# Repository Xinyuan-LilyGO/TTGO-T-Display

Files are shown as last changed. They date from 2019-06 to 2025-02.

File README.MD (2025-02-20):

# TTGO T-Display

## Quick start

1. **Install USB driver**, [CHxxx Series MAC driver](http://www.wch-ic.com/downloads/CH34XSER_MAC_ZIP.html) , [CHxxx Series Windows driver](http://www.wch-ic.com/downloads/CH343SER_ZIP.html),[CP21xx Series driver](https://www.silabs.com/developers/usb-to-uart-bridge-vcp-drivers?tab=downloads)
2.  Copy  **TFT_eSPI**  to the  **<C:\Users\Your User Name\Documents\Arduino\libraries>**  directory
3. Open **Arduino IDE,** find **TFT_eSPI** in the file and example, the **T-Display** factory test program is located at **TFT_eSPI -> FactoryTest**, you can also use other sample programs provided by TFT_eSPI
4. In the **Arduino IDE** tool options, select the development board  **ESP32 Dev Module**, **select Disable in the PSRAM option**, **select 4MB in the Flash Size option**, Other keep the default
5. Select the corresponding serial port. If you are not sure, please remove all the serial ports, leaving the board in the USB connection state, just select that one
6. Finally, click upload, the right arrow next to the tick
7. Please note that the highest version currently supported by TFT_eSPI is 2.0.14. Compiling with a version higher than 2.0.14 will result in an error. Please pay attention to the selection of esp32 version. `Tools -> Board -> Boards Manage -> Search esp32 -> 2.0.14 -> Install`

-------------------------
1. **安装 USB 驱动**, [CHxxx Series MAC driver](http://www.wch-ic.com/downloads/CH34XSER_MAC_ZIP.html) , [CHxxx Series Windows driver](http://www.wch-ic.com/downloads/CH343SER_ZIP.html), [CP21xx Series driver](https://www.silabs.com/developers/usb-to-uart-bridge-vcp-drivers?tab=downloads)
2.  拷贝  **TFT_eSPI**  到  **<C:\Users\你的用户名\Documents\Arduino\libraries>**  目录内
3. 打开**ArduinoIDE** , 在文件，示例中找到**TFT_eSPI**, T-Display出厂测试程序位于**TFT_eSPI -> FactoryTest**,你也可以使用其他TFT_eSPI提供的示例程序
4. 在**Arduino IDE** 工具选项中 ， 开发板选择 **ESP32 Dev Module**,**在PSRAM选项中选择Disable**， **Flash Size 选项中选择4MB** ，其它保持默认 
5. 选择对应的串行端口，如果不清楚请移除所有串行端口，之保留板子处于USB连接状态，选择那一个即可
6. 最后可点击上传即可，勾号旁边的向右箭头
7. 请注意，TFT_eSPI 目前支持最高版本为2.0.14 ，高于 2.0.14 编译则会报错，请注意esp32 版本的选择:`Tools -> Board -> Boards Manage ->Search esp32 -> 2.0.14 -> Install`

-------------------------
## SD card connection
- Demonstrate how to use the second SPI device, using the SD card as a demonstration device
- 使用SD卡作为演示设备,演示如何使用第二个SPI设备
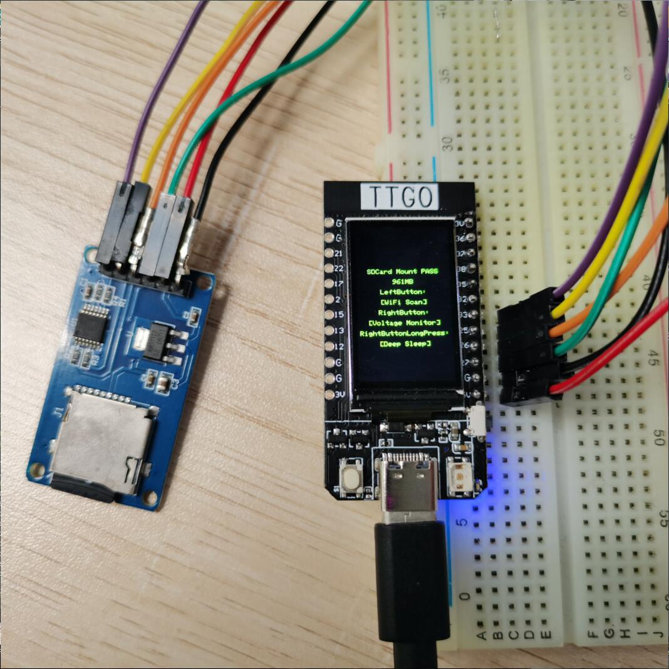
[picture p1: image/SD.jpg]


## Pinout
| Name | V18 |
| --- | --- |
| TFT Driver | ST7789 |
| TFT_MISO | N/A |
| TFT_MOSI | 19 |
| TFT_SCLK | 18 |
| TFT_CS | 5 |
| TFT_DC | 16 |
| TFT_RST | 23 |
| TFT_BL | 4 |
| I2C_SDA | 21 |
| I2C_SCL | 22 |
| ADC_IN | 34 |
| BUTTON1 | 35 |
| BUTTON2 | 0 |
| ADC Power  | 14 |

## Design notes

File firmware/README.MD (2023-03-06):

When you suspect that there is a problem with the hardware, you can brush in our test firmware

1. Download [Flash_download_tool](https://www.espressif.com.cn/sites/default/files/tools/flash_download_tool_3.9.3_0.zip)
2. Select esp32,UART
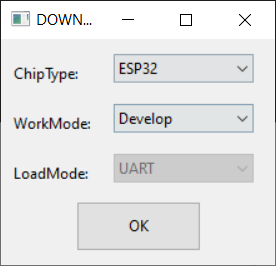
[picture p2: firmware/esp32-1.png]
    
3. Select according to the following figure, finally select START, press RST after writing, or power on again, and then observe the log output from the serial port
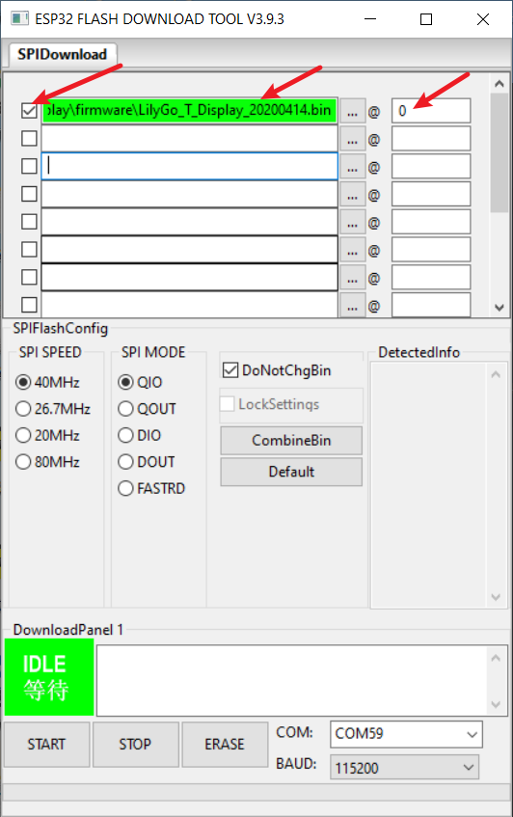
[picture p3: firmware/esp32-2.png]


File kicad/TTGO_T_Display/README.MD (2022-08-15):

# This is a KiCad library for TTGO_T_Display.
You need add "TTGO_T_Display.kicad_sym" as symbol library with name TTGO_T_Display to KiCad.
This file is in folder "symbols".
Also you need to add "TTGO_T_Display.pretty" folder as footprint library with name TTGO_T_Display to KiCad.
This folder is in folder footprints.

Library created by WolodiaM

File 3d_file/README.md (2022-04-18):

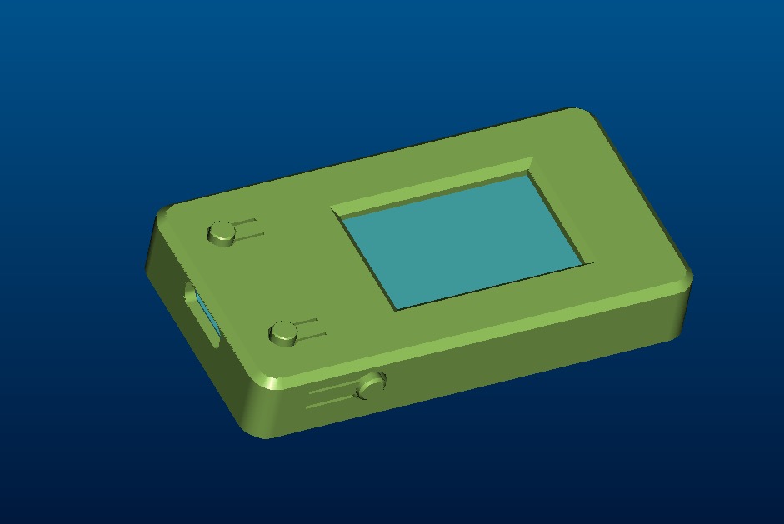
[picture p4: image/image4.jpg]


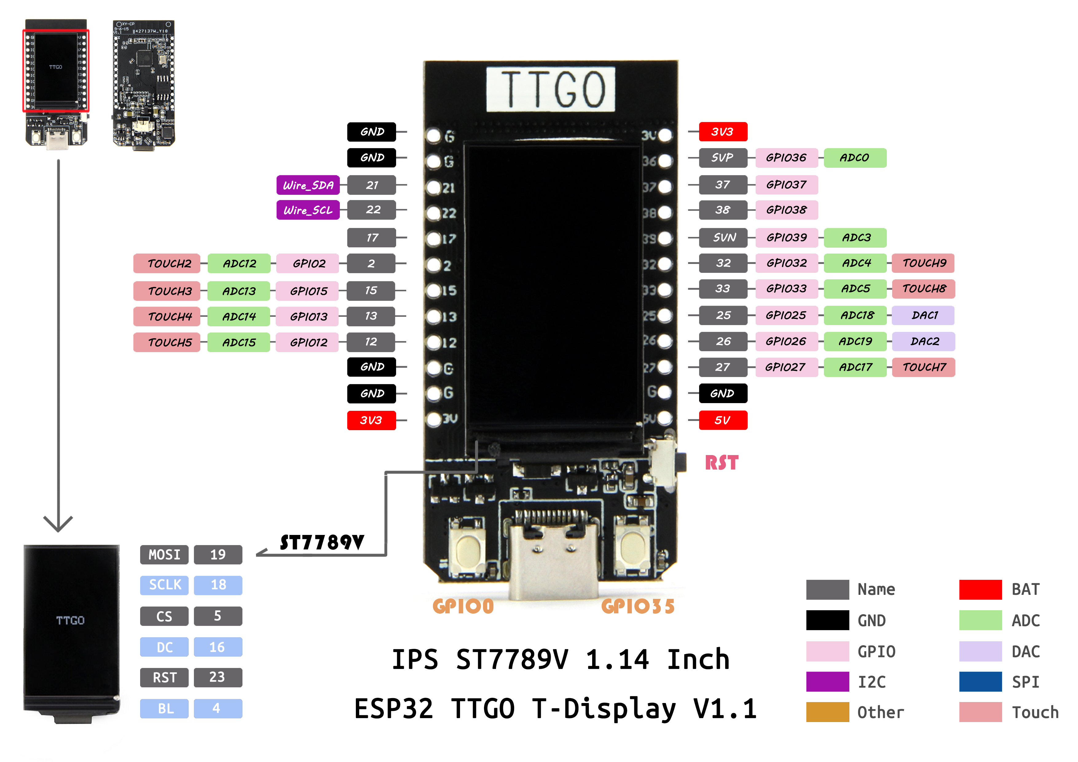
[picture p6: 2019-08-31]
image/pinmap.jpg

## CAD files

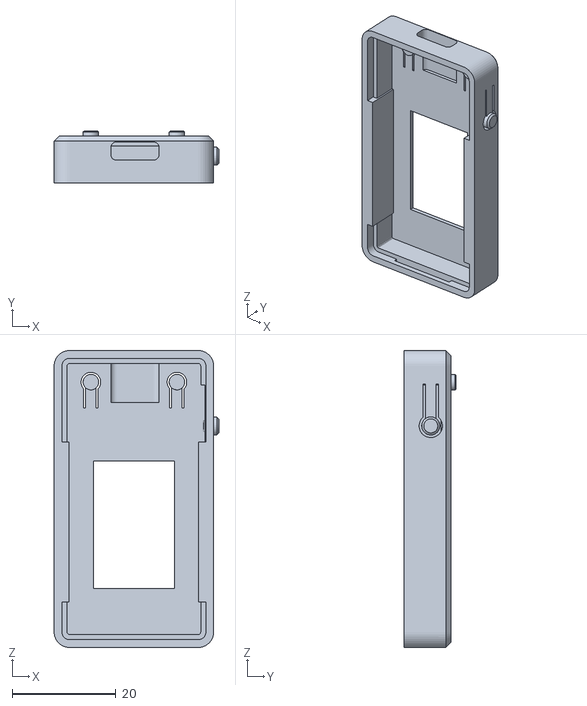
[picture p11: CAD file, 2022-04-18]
3d_file/prt0005_14(2).stl
31.8 x 10.1 x 57.3

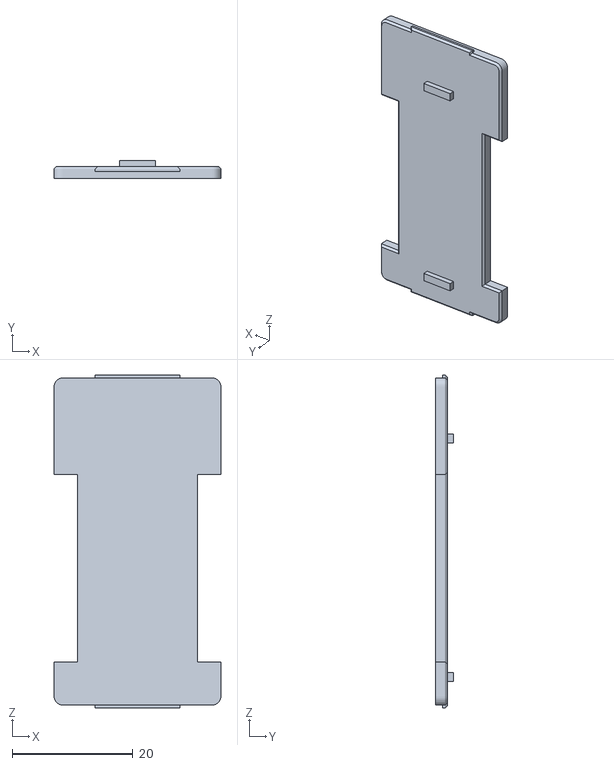
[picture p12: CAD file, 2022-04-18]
3d_file/prt0003_23.stl
27.6 x 3.00 x 55.1

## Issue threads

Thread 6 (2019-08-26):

PWR EN functionality

paccerdk, 2019-08-26:
I've been trying to figure out the functionality the PWR EN, but your schematics is difficult to figure out in this regard, and its not documented anywhere.

As far as i could figure out, the PWR EN "pin" is supposed to shut off the 3.3V regulator when powered by battery (and usb is disconected), but it does not seem to work (i've tried toggling it)

Joennuh, 2019-08-26:
Just a guess: maybe it is read only? So you can read the value and let your sketch find out in this way whether it runs from battery or USB power?

paccerdk, 2019-08-27:
@Joennuh its an output, there's a diode on the pin, restricting current flow to one direction.

gnunomad, 2019-09-22:
I have the same problem. I've been analyzing the scheme but I can't figure out how that pin works. I think the scheme contains errors in the polarity of the mosfet.

lewisxhe, 2019-10-08:
I get feedback: PWR_EN can continue to detect the power of the lithium battery when there is no USB power supply. V3V is to prevent leakage current. @paccerdk

paccerdk, 2019-11-17:
@lewisxhe
This isn't making much sense to me.
Detect in which way? As mentioned earlier, it appears to be an output, there is a [diode](https://github.com/Xinyuan-LilyGO/TTGO-T-Display/blob/master/schematic/ESP32-TFT(6-26).pdf) restricting the current flow to one direction. (out)
Could you perhaps share the feedback that you got?
Honestly, it seems to me like there is a mistake on the schematic, and the PWR_EN was supposed to be able to let the device turn itself off, when battery powered. that also explains the naming.

lewisxhe, 2019-11-18:
@paccerdk
In order to use VBA to turn on the power, because, when downloading 32, the single chip PWR_EN can not work, so V3V has no power, so 2104 can not be downloaded, so open V3V power through VBUS

The above is the original words, I am responsible for the transmission.

ricolk, 2020-03-17:
I cannot understand BAT offsheet. It is just connected to  Q4 and to the partition for battery conversion... Is it connected also to VBAT?

ticksp, 2020-04-01:
[ESP32-TFT(6-26).pdf](https://github.com/Xinyuan-LilyGO/TTGO-T-Display/files/4416932/ESP32-TFT.6-26.pdf)
For understand PWR_EN functionality you can have a look on comments, which I made in attached schematic.
So you can set PWR_EN to "1" and read voltage in BAT_ADC, if this voltage more than 4.3 V device have powered from USB. If less then 4.3 V - device have power from battery. To save battery you can set PWR_EN to "0" and in this case USB converter will be power off and do not use your battery. When you need to measure battery voltage first set PWR_EN to "1", measure voltage and then set PWR_EN back to "0" for save battery. I hope my descrition will help somebody to better use this device! :)

pvonmoradi, 2020-10-24:
@ticksp Thanks for the clarification. So the overloading of GPIO14 (as it is JTAG's TMS pin) does not hurt JTAG functionality right?
The way I see it, while debugging via JTAG, some transistors would get stressed (because of PWR EN) and the "BAT_ADC" voltage is not to be trusted, but nevertheless, this wouldn't hurt debugging.
#17 #26

tadam777, 2021-01-31:
It's possible to solder a wire on the bottom of the T-Display module to access the GPIO14. I didn't test it but here's where to solder :

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

posplayr, 2021-06-24:
Can anyone confirm that you can access IO14 at D6 in order to support JTAG and have the JTAG work?

Also it seems as if from ticksp's comment above:
**_When you need to measure battery voltage first set PWR_EN to "1", measure voltage and then set PWR_EN back to "0" for save battery._**

if not using a battery then D6 be removed and this makes it easier to solder a wire to the anode pad of D6?

kiromaisus, 2021-08-15:
Yes, it's possible to solder a pin on one end of the diode that's connected to IO14 and use JTAG. I did it with ESP-prog and it worked. Not needed to remove the diode, but I'm not using it with battery, just to debug.

posplayr, 2021-08-18:
> Yes, it's possible to solder a pin on one end of the diode that's connected to IO14 and use JTAG. I did it with ESP-prog and it worked. Not needed to remove the diode, but I'm not using it with battery, just to debug.

Thank you for that confirmation.

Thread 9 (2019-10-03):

Auto power-on when powered trough battery or 3.3v/5v pins

oniongarlic, 2019-10-03:
Is it possible to get the board to power-on automatically when powered trough the battery or 3.3v/5v pins ? At least my board requires a press of the reset button for it to start up.

When powered trough USB-C it turns on automatically, but unfortunately I can't use that in the final installation.

Joennuh, 2019-10-03:
It is actually too bad that the device hasn't got an reset-pin. When it does have an reset-pin you could attach an external reset-button to it.

lewisxhe, 2019-10-08:
This problem has been feedback, you can remove the marked position capacitance in the figure can be solved @oniongarlic
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

oniongarlic, 2019-10-10:
Thank you, I will try that.

smartynov, 2019-12-01:
@oniongarlic did it help you?

Jeopardye, 2019-12-08:
Can confirm, this works. (Which is good, because there is no way I could solder this back in. The brute force from the screwdriver probably didn't help much either...)

cc @smartynov

austrisv, 2020-01-12:
Did help for me as well ... for one or two reboots. Then suddenly it was not connecting to wifi anymore. Checked the console and upon reset can see "waiting for download" and
rst:0x1 (POWERON_RESET),boot:0x3 (DOWNLOAD_BOOT(UART0/UART1/SDIO_REI_REO_V2))

If I do upload from Arduino - it succeeds and then this. As if I would be holding gpio0 to ground on restart (where I even can't spot the gpio0 on the board).

Dear @lewisxhe, could it be related w removal of capacitor? Any other ideas what could have gone wrong? Thank You!

lewisxhe, 2020-01-13:
@austrisv Because it is GPIO0 to control the download and start, there is only the reason for this capacitor. This is the conclusion that I use the battery to connect the board and the UART output.

kostashellas, 2020-01-23:
what's the solution to this issue?
for my project I need power on when 5.3v connected to +5v pin (works only if RESET button triggered) and WiFi connection right after the power on.
C3 cap 100nF can be reduced to have both functions available?

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

john4242, 2020-02-11:
Same issue. After looking at the schematic, I'm not sure the VBUS (USB) doesn't have this power issue either, maybe the USB-TTL chip is sending an RTS signal on power or computer connection, and that is doing the reset?
CHIP_PU seems to be the reset pin on the schematic?
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

hpsaturn, 2020-05-09:
Same issue for me, after some hours, with the USB-C connected and the application running, it turn off. The only mode for turn-on it is with the reset button. It is a very bad behaivor for aplications 24/7 :'(

spiff72, 2020-05-28:
Has there been any additional info on this topic.  This is still a struggle for me.

I have several of these boards and I want to power them from the 5v pin (no battery needed).  But if they are disconnected from power, pressing the reset button to restart them is a pain.

I even see different behavior between boards (with different code loaded).  One seems to start up fine when 5v is connected to the pins, and the other goes into a state where it is drawing about 20ma of current and won't boot until the reset button is connected.

Can the code itself somehow prevent this behavior?  Or the bootloader?  The one that absolutely refuses to start without the reset button push has been loaded with a bootloader i donwloaded from a support thread from the WLED developer, so this makes me wonder if that might be contributing to the issue in my case.

spiff72, 2020-05-28:
UPDATE:  I just flashed the bootloader to the board that seems to start up correctly with the 5v pins, and after doing so, it still operates normally (no push of the button needed).

tehcaster, 2020-06-01:
> UPDATE: I just flashed the bootloader to the board that seems to start up correctly with the 5v pins, and after doing so, it still operates normally (no push of the button needed).

So what you're saying is, if the board boots on 5V pin without pressing reset, flashing the bootloader will not break that. But also if the board does *not* boot without pressing reset, flashing the bootloader also will not change that. Correct?

So the question is, what makes the difference between boards that boot and boards that don't? Of those few I have, none boots without reset. It's really a setback on otherwise great board, I wish the reset was included in the pin header. Did anyone e.g. try to desolder the built-in button and wire it away from the board?

spiff72, 2020-06-01:
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

I have an update to my previous work...
I ended up building soldering up a board (in a printed enclosure) with this TTGO T-Display over the weekend.  I am running the WLED project on it (https://github.com/Aircoookie/WLED/) - which I submitted a pull request for over the weekend as well to roll in a usermod that allows for the use of this TTGO T-Display with that WLED project and Platformio.
My arrangement is as follows:
- 12v power supply plugs into a barrel connector in the enclosure
- The 12v power supply passes through to the addressable LED strip I am using (WS2815), and I also have a small buck converter in the enclosure that drops the voltage down to 5v to power the TTGO board and a level shifter (for bumping the data signals of the TTGO up to 5v to feed the LED strip).

I just unplugged it 4 times in a row, and plugged it back in, and it powered up successfully (fully booted) without any need for a push of the reset button.

I can't recall for certain which of the boards I used for this build, but I am fairly confident that it was the one that was loaded with the clock program I referenced earlier in this thread.

I have no explanation as to WHY this is now booting without issues.  I think I did notice just one instance where it didn't boot up after initial connection to power (right after i built it), but unplugging the 12v power and plugging it back in allowed it to fire up just fine.

The only difference between this situation and the one I was testing before is that I am powering it with the 12v --> 5v buck regulator instead of my Agilent E3646A bench supply (at 5v).

This may not help others very much - but I just wanted to share my results...

sej7278, 2020-09-20:
So what's the solution to this? Seems removing the capacitor stops it from booting or something? Lots of gibberish in this thread!

sej7278, 2021-04-08:
@lamello have you tried the lipo connector?

spiff72, 2021-04-08:
Just to chime in here again, I have built several more of these WLED controllers using this board and have not had issue using the approach I described above.  I did not modify the boards in any way and they "just work" in my case.  Not sure why others don't...

lamello, 2021-04-08:
No i didn't try the lipo connector (because i will not use it in my project). As i said before i did powered directly the board with 3.3 Volt and the board won't start either.
When i look at the schema, i have a susspicion of the CP2104. The difference between powered by USB and direct (5v/3.3V) is that the CP2104 has power with the USB and not with the direct voltage. The CP2014 controls the DTR and RTS and these lines has something to do with the CHIP_PU signal. I have programmed now for several months for the project and the program  begins to get really nice, so this hardware issue is a bummer. I use almost no pins (just i2c and an pin for interrupt. I really want to use this board because is is compact and has a beautiful little display. I will look further for the issue, but i have now no problem to connect the CHIP-PU signal to an unused IO-pin and to externaly reset it (maybe with an attiny). Will see.

sej7278, 2021-04-08:
I wouldn't use a TTGO display in a final product it's just too unreliable and no two boards seem to work the same.

I'm currently prototyping on the Display  then moving to a Mini with a separate tft for the finished product

lamello, 2021-04-08:
@sej7278: What do you mean by "a Mini". I have worked with a mini, but that was a DEC PDP11. ;-)

sej7278, 2021-04-08:
TTGO T7 Mini https://m.aliexpress.com/i/32977375539.html

lamello, 2021-04-15:
Thanks for sharing.

I haven't solved it, but have now a workaround. I have made a wire from the reset switch to Pin26 (which is not used in the project).
I have programmed an attiny85 which generate a 150ms negative pulse at his startup. The attyny is powered by the 3.3Volt of the TTGODisplay. Connect the pulsepin of the attiny to pin26 of the TTGODisplay with an 120 Ohm resistor and voila, the TTGO boots when it is powered with 5Volts.
I know, it's overkill, it won't win the beauty contest. But it boots now.
I'm done with it.

Greetings lamello

trycoon, 2022-09-18:
I can confirm that unsoldering the capacitor works for three of my TTGO-T1 boards, that normally require the reset button to be pressed to power on. This is when powering the board from the 5V pins.
A fourth board works without this hack, so there may be different revisions of the board.

CLGamesStudio, 2023-03-09:
Help me please! I flashed the board several times, but after loading the Tetris game on it, it stopped being displayed on the device panel, when the PC board is connected, it sees it, but when I try to load a new program, the com port disappears from the list. Thank you in advance

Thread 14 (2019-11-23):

SPI PINs - connect to SPI device

DavidAntonin, 2019-11-23:
It is possible connect external SPI sensor - C1101 433MHz transceiver?
On generic ESP32 I use pins:
18	(SCK)
19	(MISO)
23	(MOSI)
5	(SS)
Thank you

lewisxhe, 2020-01-08:
Since 14pin of HSPI is already used, the following combinations can be used
CS 15
CLK 25 or 26,27
miso 12
mosi 13
 
21,22 is also possible, but generally used as SDA SCL for I2C

ketan, 2020-02-11:
This pin mapping definitely did not work.

```cpp
#define PIN_MISO  12
#define PIN_MOSI  13
#define PIN_SCK  26
#define PIN_CS  15
```

I'm getting the following error, it appears that the esp32 is unable to read its own memory, unplugging the microsd module seems to atleast print some debug logs via serial.

```
rst:0x10 (RTCWDT_RTC_RESET),boot:0x33 (SPI_FAST_FLASH_BOOT)
flash read err, 1000
ets_main.c 371
ets Jun  8 2016 00:22:57
```

Has anyone managed to get an sd card to work with this TTGo board, could you share your pin mappings?

ketan, 2020-02-11:
Found the answer, the following pin mappings worked for me:

```
#define PIN_MISO  27  // GPIO27
#define PIN_MOSI  26  // GPIO26
#define PIN_SCK   25  // GIPO25
#define PIN_CS    33  // GPIO33

...
SD.begin(PIN_CS, PIN_MOSI, PIN_MISO, PIN_SCK)
```

romatou18, 2020-03-03:
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

I found out the same thing: trying to use the remaining available HSPI pins i.e. 15,13, 12 does NOT work at all. Tried it very hard, the only thing that works is using other generic GPIOS with the VSPI, although it's not as good as HSPI since the max clock speed is only 26MHZ if im correct vs. 40MHZ for HSPI. But using an SD card reader on SPI seems to work great, decent writing speed, way enough for logging text.

If it was coming to writing a video stream real time from a camera that would likely be an issue. Anyway other modules like the TTGO Camera module are made for that.

Now the big problem that remains is the fact that PIN 14 is the MS JTAG pin and therefore this is impossible to do JTAG debugging on TTGO-T Display. I found that out too late. Not an issue for production once the program works ok. But for development work this is a real issue. I am now thinking of developing my project on a different board.

RideOn123, 2020-05-09:
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

Which SD Libary did you use? The "standard" Lib expects different arguments for SD.begin().

ketan, 2020-05-09:
I'm using Arduino api on esp32:
https://github.com/espressif/arduino-esp32/blob/master/libraries/SD/src/SD.h

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

minkione, 2020-05-28:
I am trying to get working a CC1101 with my T-Display.
Someone suggested to device the following pins as SPI for teh connection between the T-Display and the NRF24...
MISO: 27
MOSI: 26
SCK: 25
CSN: 33
GDO0: 2
GDO2: 37
But it still doesn't work.

Anyone has some suggestions?

lewisxhe, 2020-06-28:
@minkione

As shown in the code below, did you specify SPI to initialize it?
```
#include "FS.h"
#include "SD.h"
#include <SPI.h>

SPIClass SPI1(HSPI);

#define MY_CS     15
#define MY_SCLK   25
#define MY_MISO 26
#define MY_MOSI 27
void setup()
{

    SPI1.begin(MY_SCLK, MY_MISO, MY_MOSI, MY_CS);

  //Assuming use of SPI SD card
    if (!SD.begin(MY_CS, SPI1)) {

        Serial.println("Card Mount Failed");

    } else {
        Serial.println("DEU CERTO INICIAR SD CARD");
    }
}
```

minkione, 2020-06-28:
Yes, I defined them in my sketch:
```
//ELECHOUSE_cc1101.setSpiPin (SCK, MISO, MOSI, CSN);
ELECHOUSE_cc1101.setSpiPin(25, 26, 27, 15);  //Default LSatan Configuration For T-Display
```

In case you wanna try with a CC1101, I used this sketch
https://github.com/LSatan/SmartRC-CC1101-Driver-Lib/blob/master/examples/Rc-Switch%20examples%20cc1101/ReceiveDemo_Advanced_cc1101/ReceiveDemo_Advanced_cc1101.ino

from the https://github.com/LSatan/SmartRC-CC1101-Driver-Lib

minkione, 2020-06-28:
For instance, I tried with different boards, ESP32 Wroom, ESP8266, UNO R3, MEGA2560.
The only board so far that doesn't work and cannot figure out why the SPI pins do not work... is the T-Display one...

minkione, 2020-06-28:
I have even added this:
  SPIClass SPI(HSPI);

here:
https://github.com/LSatan/SmartRC-CC1101-Driver-Lib/blob/master/ELECHOUSE_CC1101_SRC_DRV.cpp#L69
```

/****************************************************************
*FUNCTION NAME:SpiStart
*FUNCTION     :spi communication start
*INPUT        :none
*OUTPUT       :none
****************************************************************/
void ELECHOUSE_CC1101::SpiStart(void)
{
  // initialize the SPI pins
  pinMode(SCK_PIN, OUTPUT);
  pinMode(MOSI_PIN, OUTPUT);
  pinMode(MISO_PIN, INPUT);
  pinMode(SS_PIN, OUTPUT);

  SPIClass SPI(HSPI);

  // enable SPI
  #ifdef ESP32
  SPI.begin(SCK_PIN, MISO_PIN, MOSI_PIN, SS_PIN);
  #else
  SPI.begin();
  #endif
}
```

minkione, 2020-06-28:
And to be sure... I also tried by replacing all existing occurrences of "SPI." with "SPI1."

https://gist.github.com/minkione/795307620dbb93723678fcec3ff19368

No luck in getting CC1101 working...

lewisxhe, 2020-06-29:
I have tried using the SD card and everything is working, the code and README have been updated

pati5000, 2020-07-08:
@minkione you swapped the MISO and MOSI pins by mistake.

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

See the original post from @ketan

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

Hope this helps. All the best

flyandi, 2020-07-29:
So for anyone still having issues. Both HSPI and VSPI are working BUT you need to ensure you connecting  it right. I had issues with the actual pin-out of using an TF Card Holder and just "blindly" followed the pictures. Turns that both are wrong.

Here is the correct pin out on both the Micro SD and the adapter:

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

Biggest feedback is there that PIN 1 is NOT CS.. I repeat PIN 1 is NOT CS .. PIN 1 is not used for SPI and PIN 2 is CS .. after that it worked without flaws both on HSPI (40mhz) and VSPI (26mhz) ...

tadam777, 2021-12-12:
>

Just confirm it's possible to JTAG debug by soldering the required IO14/TMS pin under the board : https://github.com/Xinyuan-LilyGO/TTGO-T-Display/issues/6#issuecomment-770394385

Closed 2020-06-29.

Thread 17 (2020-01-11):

is there a way to connect JTAG debugger to the processor on this board ?

anonymouze, 2020-01-11:
I can't see any JTAG pins in the schematics. Need to set up a debugger.

lewisxhe, 2020-01-13:
Unfortunately, JTAG cannot be used for debugging

bastianhjaeger, 2020-05-28:
Is there any other way of debugging? E.g. via the USB?

pvonmoradi, 2020-10-24:
@lewisxhe Out of 4 required JTAG pins, only GPIO14 (MTMS/TMS) is not available. What is this "PWR EN" that is connected to it? Following the schematics, it seems it is attached to D6 diode.

tadam777, 2021-01-31:
To test but the pin GPIO14 can be accessed under the board : https://github.com/Xinyuan-LilyGO/TTGO-T-Display/issues/6#issuecomment-770394385

robertlipe, 2021-03-14:
If you need JTAG in this form factor, the Longan Nano does have JTAG brought opposite the USB connector, making it a real pain on breadboard since

I wish I'd noticed lewisxhe's comment before, as I ordered this to step up (over?) from Longan Nano just in the hopes of having a better video display controller. That sentence really puts the hurt on using this in development.

I was just told by B*d that this device was discontinued. I can't tell if that's from them or by the maker, but they DO seem to be getting rarer.

Off to Plan D for an inexpensive, self-contained RISC-V development/debugging environment with a screen.

robertlipe, 2021-03-14:
@lewisxhe , now that I look at it, are you sure? I'm looking at the Longan Nano and my (dysfunctional) T-Display and all the JTAG pins are in the same place.  In the GD32V Manual (500+pages), section 7.4.3 says the packages with low pin count (e.g. the one used here) can be reconfigured to remap the JTAG from (non-existent) pins.  The mappings are exactly the silk screens on this board and in the same location as they are on the Nano. 7.3.1 and 10.2.1  says the startup values of the GPIO lines out of reset should work for JTAG.

7.5.9 shows that SWJ_CFG[2:0] defaults to remapping being on and "The default state after reset is SWJ
ON.This allows JTAG mode to be enabled by sending a specific sequence on the JTMS/JTCK pin."

I wonder if this really IS the same as the NANO and it's just a silkscreen labeling issue that makes it look like JTAG isn't available.

TMS is one of those that gets remapped.

Can anyone with a working board try the pinouts from https://wiki.segger.com/SiPeed_Longan_Nano or offer a definitive reason why this doesn't work?

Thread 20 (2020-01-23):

Unable to read the battery voltage when USB is disconnected

yellowbeak, 2020-01-23:
When power is connected via USB, I can read the ADC value on pin 34, which is the BAT_ADC signal on the schematic and is half the supply voltage.

However, if I connect a LiPo battery, and disconnect the USB, this pin always returns a value of 0.

I have tried setting pin 14, which is PWR_EN as an output, and setting both HIGH, and LOW, but neither of these change the value I'm reading from pin 34 - it always reads 0 when running from battery.

How can I read the battery voltage when running from the battery without the USB connected?

bbogdanmircea, 2020-01-24:
I have just tried this board yesterday with the code from master and it shows the battery voltage on the display even when USB is not connected.
What code are you running on the board?

yellowbeak, 2020-01-24:
Sorry - you are correct.  I went back to the original example and it works as expected.  I was using a modified version of this, that incorrectly reconfigured one of the pins by trying to read it as a touch input, which gave the problem that I was seeing.  Once I removed this, it all works as expected.
Please delete this issue thread.

Closed 2020-01-24.

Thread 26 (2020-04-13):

PWR_EN on IO14

mhannebert, 2020-04-13:
I'm not sure what the "PWR_EN" is for...

It is connected to IO14
In the demo code, there is  a "#define ADC_EN 14" but this ADC_EN is not used further...

It is related to the ADC ? I don't think so. To measure the voltage of battery, this is IO34.
It looks like it is triggering one MOSFET which is linked to the battery?

mhannebert, 2020-04-15:
The demo code was updated in this respect just a few days after my comment above.

It looks like the PWR_EN set to HIGH enables to measure the batterie itself. Otherwise, it measures the voltage provided by USB? I'm not sure.

Not tested yet.

pvonmoradi, 2020-10-24:
Same question here. Since GPIO14 is JTMS, this essentially causes the board to lose support for JTAG debugging.
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

tadam777, 2021-01-31:
It's not too complex to access this pin and/or remove the diode : https://github.com/Xinyuan-LilyGO/TTGO-T-Display/issues/6#issuecomment-770394385

bbogdanmircea, 2021-02-16:
Can anybody explain according to the schematic what happens when this PWR_EN is high or low?

jej, 2021-02-27:
Here: #6

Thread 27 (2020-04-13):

How to power the board?

mhannebert, 2020-04-13:
I want to power the board without the USB.

Should I provide 5V to the "5V" pin?
Should I provide 3.3V to one of the "3V3" pins?
Would any of the above work?

I guess that if I provide 3.3V, the battery won't charge. But will it charge if I provide 5V?
It looks to me that only USB, through the TP4054, would enable the battery to charge...

M

JoeBarouneD, 2020-04-13:
Like any ESP32, you "normally" can power it by 5V or 3.3V.
I don't know if it can "step up" from 3.3v to Vcharg, you can try and report the result.
But i think it will work without problems on 5V.

flyandi, 2020-04-15:
I run it off a 1s lipo without issue.

spiff72, 2020-05-27:
Rather than attempting to create a new issue - I am looking for some help here.

In order to power this TTGO T-Display board with a voltage source (not through the USB-C connector), how would one go about this?

Are you connecting 5v to the 5V pin?  Or 3.3V to the 3.3V pin?  The 3.3v pin appears to be the output of the 3.3V regulator, so I am not sure that is the right approach.

And from my (unprofessional) look at the schematic, it seems like a 5V source would ideally be connected to the VBUS line, but that isn't broken out to a pin.

Am I missing something here?

I was hoping to use these for a project where I mount it in an enclosure, with a 12V input from a wall wart, and a small buck regulator to drop the voltage to 5v to power this and a level shifter for controlling some 12v addressable LEDs.  But not being able to power from that 12V source makes this board a bummer for me.  Even if it could be externally powered with a 3.3v source, I could put a second buck regulator in there for the 3.3v source and make it work.

But I have also seen some mentions that the board doesn't start "automatically" when power is applied through a method outside of the USB-C port.

JoeBarouneD, 2020-05-28:
Powering it by the JST connector is working (you can put a 18650 bat to test).
I could power it by USB-C with some voltage range.

Powering it by the 5V should work.
Just try it.

sej7278, 2020-09-20:
I can't get the battery connector on the underside to turn on the display, it seems to run a IR-LED i have hanging off the 5v pin (and I assume the ESP32 itself) but I can only get the display to turn on when running from USB-C. Does the display need 5v?

ribbles, 2020-10-31:
If I power via 5v rail, 5.0v is sent to the LiPo battery, so it looks like it is passing battery management. If I power via USB-C, 4.2v is sent to the LiPo battery. So I am unable to use battery management unless using the USB-C port, since there is no VBUS connector. I guess I could remove the USB connector and solder on to that, but that just makes it difficult to improve the software later on.

@sej7278 - I am able to run the controller & screen using just a LiPo battery plugged into the JST port, and also via the 3.3v rail.

I am using this schematic for reference: [https://raw.githubusercontent.com/Xinyuan-LilyGO/TTGO-T-Display/master/schematic/ESP32-TFT(6-26).pdf](https://raw.githubusercontent.com/Xinyuan-LilyGO/TTGO-T-Display/master/schematic/ESP32-TFT(6-26).pdf)

sej7278, 2020-10-31:
@ribbles when you run the controller and screen using a lipo, do you need to press the reset button to make the screen come on?

ribbles, 2020-11-01:
No. But my board was shipped without a capacitor next to the USB-C port, which I read is what needs to be removed here: [https://github.com/Xinyuan-LilyGO/TTGO-T-Display/issues/9](https://github.com/Xinyuan-LilyGO/TTGO-T-Display/issues/9)

madameczek, 2021-03-10:
> If I power via 5v rail, 5.0v is sent to the LiPo battery, so it looks like it is passing battery management. If I power via USB-C, 4.2v is sent to the LiPo battery.
...
> I am using this schematic for reference: https://raw.githubusercontent.com/Xinyuan-LilyGO/TTGO-T-Display/master/schematic/ESP32-TFT(6-26).pdf

Are u sure that 5V from rail is passed to a batterry connector or U6 batt management chip? I didn't test, but can't see this from schematic.

ismailagir, 2021-04-18:
Do 3.3V output also works when a lipo is connected?

ribbles, 2021-04-19:
Yes.

AdamM68, 2021-04-20:
still there is NO answer how to power the board/display other way than the USB-C connector.
I'm also looking for the easy answer - solution : how to power this device (not by USB-C) ?
- which pin should I use with 5v to make it work the same way as it works during USB-C powering ?
-

tadam777, 2021-04-30:
I'm powering it by the 5V pin, without using a battery or USB and it works fine.

itamardv, 2021-05-24:
Still without answer about how to use a battery and the back connector to power this thing?

dan-glass, 2021-05-24:
I connected the supplied power connector cable to a 4.7v lithium battery, and charge via the USB port. Works reliably and performs battery management.

perlix, 2022-07-26:
Two T-Display boards that I bought in early 2020 cannot be powered over their 5V pin. Three recently bought ones can, so there may have been a revision.

Shohreh, 2022-11-26:
I know nothing about electronics.

The TTGO has no on/off switch for the battery.

What compact switch could I use, so that I don't have to plug/unplug the JST cable each time?

Thank you.

flashtel, 2022-12-09:
I tried powering via the 5vdc and one of these

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

The GPS has 12 satellites but keeps loosing fix.

I plug the USB in disconnect the 5v drive, rock solid fix. Bring it in side it get's down to 4 sats and has rock solid fix.

It's also show batt volts when there is no battery attached when you drive it via the via 5 volt pin.

I'm going to either modify a USB plug or try and get something onto the back of the USB.

Thanks

codiak6335, 2023-01-03:
5v on the 5v pin just fried the board.

While I don't mind paying for learning... the time it takes to replace the boards... ARGH

Has any got a reliable solution?  can I power the 3.3v with 5v safely?

flashtel, 2023-01-03:
Hi,

I cooked mine also.

The only solution I can come up with is power it directly through the USB port.

I tried to pick up the line behind the USB connector but it was too fine for my soldering iron.

https://github.com/Xinyuan-LilyGO/LilyGo-LoRa-Series/blob/master/schematic/LilyGo_TBeam_V1.1.pdf

I would buy a mini usb connector and power it through there.

It's going to be ugly with a usb connector sticking out but I wish I had done that, rather than where we are both now.

After I fried it, I tried to replace the AXP192 chip, I think the problem is down stream from that, it didn't work.

I then tried a T-Motion board, which worked really well for about 7-8hours then it lost GPS fix, restarted wouldn't work.

Waited overnight, restarted it worked for another 7 hours and now the GPS is coming up as not recognised on boot.

I checked all the voltage test points and the 5v supply for noise/spikes looks good.

I have a badge/t-echo as well, it works really well with low GPS signal, I think the quectel L73K GPS is better than the Ublox M8N, after about 30 hours the e-paper screen has gone U/S.

3 out of 3 hardware faults.

I spent a lot of time on this, not sure I want to spend anymore.

Thanks

From: "Charles Jones" ***@***.***>
To: "Xinyuan-LilyGO/TTGO-T-Display" ***@***.***>
Cc: "paul" ***@***.***>, "Comment" ***@***.***>
Sent: Tuesday, 3 January, 2023 11:05:54 AM
Subject: Re: [Xinyuan-LilyGO/TTGO-T-Display] How to power the board? (#27)

5v on the 5v pin just fried the board.

While I don't mind paying for learning... the time it takes to replace the boards... ARGH

Has any got a reliable solution? can I power the 3.3v with 5v safely?

—
Reply to this email directly, [ https://github.com/Xinyuan-LilyGO/TTGO-T-Display/issues/27#issuecomment-1369348359 | view it on GitHub ] , or [ https://github.com/notifications/unsubscribe-auth/AEDG3I2ECRRX7GLBKJQ4MP3WQOJRFANCNFSM4MG24SLQ | unsubscribe ] .
You are receiving this because you commented. Message ID: ***@***.***>

codiak6335, 2023-01-03:
I can add a 5v to 3.3v regulator inline... but seems a waste

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

--
Cheers,
    Chuck

"It's not about how deep you went; it's about how long you stayed."

Rule the bottom - Rebreathers!

Esantacruz01, 2023-02-15:
I had the same problem to power the board/display other way than the USB-C connector. Some boards doesn't work powering 5V from external. The board just works from USB-C connector.
Solution: To power from battery or from external source you need to add these two lines at beginning of your coding setup() function (Arduino IDE). Lines are pinmode(15,OUTPUT); digitalWrite(15,1);
Thios will enables the pin for external power.
I hope that helps.

elpidiovaldez, 2023-03-02:
Is it not possible to power the board from 5V connected via the JST ? As far as I can see the charger chip (TP4054) allows battery voltage in range -0.3-7V, so 5V should not be a problem.  It is not going to try to charge a battery at that voltage, even if USB power is connected.  The 3.3V regulator allows input up to 6V, so that should continue to work.  I believe the other circuitry should prevent the USB supply fighting the battery input.  Am I missing anything ?  Has anyone tried it ?

Esantacruz01, 2023-03-02:
> Is it not possible to power the board from 5V connected via the JST ? As far as I can see the charger chip (TP4054) allows battery voltage in range -0.3-7V, so 5V should not be a problem. It is not going to try to charge a battery at that voltage, even if USB power is connected. The 3.3V regulator allows input up to 6V, so that should continue to work. I believe the other circuitry should prevent the USB supply fighting the battery input. Am I missing anything ? Has anyone tried it ?

Hi Valdez.
I am unable to power up from the JST too.
Looks like this issue is related to some version revision of these boards....Some works, some doesn't. My lot of 10 boards just powers up from the USB-C. That's why you need to add the lines above in your coding...

elpidiovaldez, 2023-03-03:
What does GPIO15 do ?  On my schematic it does not appear to be connected to anything.

jessedmatlock, 2023-04-22:
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

Thank you for the clarification!

erazor83, 2023-09-04:
Thanks for this issue. I also was wondering how to power via external 5V.

Using the battery input did not work for me. Fortunately I also didn't fried my board cos I noticed it's getting warm when I connect to the 5V PIN.

I connected an unused NC PIN directly to PIN 4 of the charger, see attached photos.
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

Achref-omrani, 2024-02-05:
> Powering it by the JST connector is working (you can put a 18650 bat to test). I could power it by USB-C with some voltage range.
>
> Powering it by the 5V should work. Just try it.

Does this apply for both lipo and lion batteries ? It only needs to be 3.7v that's it the type do not matter ?

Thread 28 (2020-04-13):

Eagle library

mhannebert, 2020-04-13:
Did anyone create the library for use of this board in an Eagle project?

If not, I'm going to do it and share ;)

flyandi, 2020-04-15:
I made one a while ago. Attached. Also added as PR.

https://github.com/Xinyuan-LilyGO/TTGO-T-Display/pull/29

[TTGO-TDisplay.lbr.zip](https://github.com/Xinyuan-LilyGO/TTGO-T-Display/files/4478957/TTGO-TDisplay.lbr.zip)

flyandi, 2020-04-15:
This footprint has been tested in a real PCB btw. So it works.

mhannebert, 2020-04-15:
Thanks @flyandi
I may work a little on it - and will post it back here

May I ask? How did you power up the device? 3.3V on one of the 3V3 pins?

flyandi, 2020-04-15:
Through the USB-C connector or the battery connector on the backside.

mhannebert, 2020-04-20:
Here is the library I created based on flyandi's.
I did not tested it yet but I'm pretty sure that it is correct.

[TTGO T-Display.lbr.zip](https://github.com/Xinyuan-LilyGO/TTGO-T-Display/files/4504282/TTGO.T-Display.lbr.zip)

Would be nice to put a message if you used it.

M

flyandi, 2020-04-20:
Nice work. I will be updating my lib with this as well.

joanbono, 2020-04-26:
Just for the record, I used SnapEDA to convert the library from Eagle to KiCAD.

Thanks a lot guys (@flyandi @mhannebert )!

Attached:

[MODULE_TTGO_T-DISPLAY.zip](https://github.com/Xinyuan-LilyGO/TTGO-T-Display/files/4535701/MODULE_TTGO_T-DISPLAY.zip)

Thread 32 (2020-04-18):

Which PINS are free to use for another SPI device?

minkione, 2020-04-18:
Hi,
Which pins are still free from the TFT in order to be connected to another SPI device?

JoeBarouneD, 2020-04-20:
#14 See [this answer](https://github.com/Xinyuan-LilyGO/TTGO-T-Display/issues/14#issuecomment-584471342).

minkione, 2020-04-20:
thanks! Will give it a try.
Quick question, since I will need also 2 more free spare GPIOs...
Which are the GPIOs that can still be used overall?

JoeBarouneD, 2020-04-20:
You can use almost all other GPIOs.
Have a look at the Pinmap. Many GPIOs are free.

minkione, 2020-04-20:
I am asking because respect the usual ESP32 the pinouts for SPI doesn't look the same.
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

Versus the T-Display... (marked in red the pins in scope)
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

minkione, 2020-04-20:
Here I am comparing the ESP32 pinout and the pinouts from the T-Display schematics.
Now makes everything more clear. Though a doubt still remain regarding VSPI and HSPI... how do you enable the VirtualSPI (VSPI)? Just connect the device to those Pins and then declare in the sketch and everything works?

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

flyandi, 2020-07-29:
HSPI is only on 27,26,25 (MOSI, MISO, SCLK)  - at least from my experimentation .. CS pin can be anything.
VSPI can be on any free pin..

siriokds, 2021-06-08:
I used this for sd card access.

SPIClass spiSD(HSPI);

pinMode(2, OUTPUT);
spiSD.begin(13,12,15,2);       //SCK,MISO,MOSI,SS

raomin, 2022-02-08:
I wanted to connect a second display (ILI9341) on a secondary SPI.
While 27,26,25 (MOSI, MISO, SCLK) and 33 CS is ok, I found out that the pins 37 38 39 do not work for DC (Data command), RST (Reset) (or CS...)
Pins on the other side (17,2,15,12) works for DC, RST etc.

I ended up with:
```c
#define ILI9341_DRIVER

#define USE_HSPI_PORT
#define TFT_MISO  27
#define TFT_MOSI  26
#define TFT_SCLK   25
#define TFT_CS    2

#define TFT_DC   33  // Data Command control pin
#define TFT_RST  32  // Reset pin (could connect to NodeMCU RST, see next line)

```

lockie555, 2023-07-23:
I am having an issue with using 3 devices (SD, 9341TFT, & RM3100) on SPI on a TTGO-T4v1.3.
My code works fine on a STM32 Nucleo152 but I cannot get the SPI bus to work on the T4. As the SD and TFT are built in on the T4, I only have access to the jumper pins and I chose SCLK-32; MISO -35; MOSI-34; CS-33 for my RM3100 magnetometer sensor.
The documentation re SPI on the T4 is a bit lacking, and I assume the SD and the TFT are both on default VSPI. I have tried the RM3100 as a HSPI but got nowhere; nor does it work as a VSPI. The TTGO-T4 pinout diagrams show the SD using SCLK -14, MISO-02, MOSI-15, CS-13 which are not the HSPI defaults and the TFT using SCLK -18, MISO-12, MOSI-23, CS-27 which are not VSPI defaults.
I tried LewisXHE's code for SD with the TTGO-T display and had no luck with that either. I am not sure whether the problem is a lack of understanding by me. I learn by example and I haven't been able to find any examples of external sensors using SPI on T4. Any ideas?

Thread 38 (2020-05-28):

SPI Pins (27,26, 25, 33) do NOT work with external SPI device

minkione, 2020-05-28:
I am trying to get working a CC1101 with my T-Display.
Someone suggested to device the following pins as SPI for teh connection between the T-Display and the NRF24...
MISO: 27
MOSI: 26
SCK: 25
CSN: 33
GDO0: 2
GDO2: 37
But it still doesn't work.

Anyone has some suggestions?

lewisxhe, 2020-06-28:
@minkione

As shown in the code below, did you specify SPI to initialize it?

```
#include "FS.h"
#include "SD.h"
#include <SPI.h>

SPIClass SPI1(HSPI);

#define MY_CS     15
#define MY_SCLK   25
#define MY_MISO 26
#define MY_MOSI 27
void setup()
{

    SPI1.begin(MY_SCLK, MY_MISO, MY_MOSI, MY_CS);

  //Assuming use of SPI SD card
    if (!SD.begin(MY_CS, SPI1)) {

        Serial.println("Card Mount Failed");

    } else {
        Serial.println("DEU CERTO INICIAR SD CARD");
    }
}
```

lewisxhe, 2020-06-29:
26,27 has been used, can not be used 26,27, you need to replace the pin

minkione, 2020-06-29:
In a SPI bus... there could be multiple slaves connected to the same MISO and MOSI and SCK.
What is important is to have a different CSN for each slave...
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

minkione, 2020-06-29:
That means that 26 and 27 must be used for both devices connected to the SPI bus.

lewisxhe, 2020-06-29:
Sorry, I thought you had another board, I made a mistake. I will briefly test it later.

minkione, 2020-06-29:
No problem :)
Actually after playing a bit I managed to get it work the CC1101.
But when I try to use BOTH CC1101 and the TFT Display... it fails badly to compile.

I uploaded here the sketch and the libraries needed, in case you wanna have a look.
https://mega.nz/file/XEpXHb7A#rRXXcQ3D_pqLUPbAJQ455SL8r6hnwBaLgqQHPIcnbYM

P.S. Maybe is worth keep discussing in the other issue https://github.com/Xinyuan-LilyGO/TTGO-T-Display/issues/14 and closing this one.

lewisxhe, 2020-06-29:
I have tried using the SD card and everything is working, the code and README have been updated
@minkione

minkione, 2020-06-29:
Thanks anyway. I already opted for a MEGA2560 with a 3.2" TFT....
That had proper documentation  a month ago...

Closed 2020-06-29.

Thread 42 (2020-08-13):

PIN14 / 80MHZ SPI

flyandi, 2020-08-13:
So I am looking at the schematics and for some unknown reason the only pin to make 80MHZ IOMUX SPI possible is taken away for voltage measurement.

Is there any particular reason for that or is that something that LilyGo potential could change so we could use 80MHZ SPI .. for radical fast reading / writing speeds on SPI?

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

Thanks,

inoperable, 2020-08-13:
You can use pins 25, 26 and 15, for example;
```
#define CLK_PIN    25
#define MOSI_PIN  26
#define MISO_PIN  27
#define CS_PIN      15
```

CS can be remapped to (almost) any other not used GPIO.
Im running the board with 2 * 4 in 1:8x8 Max7219 DotMatrix modules in a chained config,
aside from connecting an extra power supply to run the DotMatrix (the drain too much the ESP32 pins)
the board seems to be working fine - allthough I didn't initialized the built-in OLED, but this should work
with it as well (gonna update as soon as I put a test of the OLED & MX7219 together)

flyandi, 2020-08-13:
But those are not IOMUX pins so you are limited to max 40mhz.

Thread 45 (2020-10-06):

Control Backlight intensity

arduibag, 2020-10-06:
Do you have a feature to control the TFT backlight intensity? (with PWN management)

AReubens, 2020-12-03:
Yes, I was looking for this too, check out line 118 of User_Setup.h (and the comments before it):
```
#define TFT_BL   32            // LED back-light control pin
```

Then using the PWM controller on the esp you can change the backlight brightness:

```
ledcSetup(ledChannel, freq, resolution); // 0-15, 5000, 8
ledcAttachPin(TFT_BL, ledChannel); // TFT_BL, 0 - 15
ledcWrite(ledChannel, brightness); // 0-15, 0-255 (with 8 bit resolution)
```

Check out this [PWM on ESP32 tutorial](https://randomnerdtutorials.com/esp32-pwm-arduino-ide/) for more info

arduibag, 2020-12-03:
Thanks a lot!
For the frequency, it says "For an LED, a frequency of 5000 Hz is fine to use." but how is it calculated? Do you know?

rin67630, 2021-03-15:
Hi @AReubens,

Why do you recommend to check out line 118 of User_Setup.h?
TFT_BL is defined elsewhere it works without that.

rin67630, 2021-03-15:
Due to the specificity of the ESP32 to have 16 assignable  PWM controller channel, the user must define a channel to use.
The library should not use a channel on its own.

capedra, 2021-10-03:
On the file "Setup25_TTGO_T_Display.h", we can see that TFT_BL pin uses GPIO4. So, on User_Setup_Select.h file, we uncomment the following line:
```#include <User_Setups/Setup25_TTGO_T_Display.h>    // Setup file for ESP32 and TTGO T-Display ST7789V SPI bus TFT```
 And after that, it's just a matter of controlling the brightness, which basically is:
```
pinMode(TFT_BL, OUTPUT);
ledcSetup(0, 5000, 8); // 0-15, 5000, 8
ledcAttachPin(TFT_BL, 0); // TFT_BL, 0 - 15
ledcWrite(0, 1); // 0-15, 0-255 (with 8 bit resolution); 0=totally dark;255=totally shiny
```

rin67630, 2021-10-04:
> For the frequency, it says "For an LED, a frequency of 5000 Hz is fine to use." but how is it calculated? Do you know?
Everything above 100Hz is fine.

nOfOKUz, 2023-05-14:
Hi,
Thanks for that tricks, that was what I was looking for.
Thought I am not seing any intensity changes on my TTGO screen going from 0 to 255. Is there something I missed? Is it working for you.
TT

hasaranga, 2024-09-05:
same here...

hasaranga, 2024-09-05:
Found the issue. you need to set brightness after tft.init() function call.

  pinMode(4, OUTPUT);
  analogWrite(4, brightnessLevel);

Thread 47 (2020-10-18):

Implementing UART connection

DevilRulerEx, 2020-10-18:
Hello, I'm new to this.

With Arduino UNO, there are TX and RX pins for me to establish UART connection.

Which pins can I use to for TX and RX? Thanks.

DevilRulerEx, 2020-10-18:
Found the solution to my own issue,

This is a comment from banggood that has helped me:

A "standard" ESP32 has more pins, the default pins are 3 (Rx) and 1 (Tx) for Serial(0), 9 (Rx) and 10 (Tx) for Serial1, and 16 (Rx) and 17 (Tx) for Serial2. As you can see, with the limited number of pins on this TTGO board, none of them are there. But the good news is that the "Serial.begin" function has an option to change the pins! By using "Serial2.begin(9600, SERIAL_8N1, 25, 26);" you have the Serial2 port on pins 25 (Rx) and 26 (Tx). I tested this today, it's working like a charm!. It's NOT working on pins 37 and 38 (and maybe other pins), but it IS working on pins 25, 26, 27 !!!

tadam777, 2021-01-31:
Notice that GPIO pins 34 to 39 are input only, so they can be used for RX but not for TX.

henriquegmatos, 2021-12-16:
Please, There is a default pins to Serial2 or Serial1 on this board?

I´m try to use it as MIDI controller using MIDI.h on IDE Arduino. However I dont get define this pins (25, 26 or 27) to Serial to be used by MIDI.h library.

I try

`struct Serial2MIDISettings : public midi::DefaultSettings
{
  static const long BaudRate = 31250;
  static const int8_t RxPin  = 25;
  static const int8_t TxPin  = 26;

};

MIDI_CREATE_CUSTOM_INSTANCE(HardwareSerial, Serial2, MIDI, Serial2MIDISettings);`

but not works. Anybody could help me?

Thanks

rigr, 2023-02-12:
I'm facing similar problems using the TTGO-T Display board when using MIDI, WiFi and the display. I can not use the display at the same time I use MIDI. The following part works (I know, defining Serial2 is reduntant) but the display stops when it is called.
If using serial1 the board crashes. I'd love to use ths board for a MIDI-application WITH the display. I can only use it to send notes if I use AplleMIDI, but I'd love to use DIN-MIDi.

Anybody out there with a hint?

I also use those libraries:
```
#include <SPI.h>
#include <TFT_eSPI.h>
//
TFT_eSPI tft = TFT_eSPI();
```

Andf this is the code:

```
struct SerialMIDISettings : public midi::DefaultSettings {
  static const long BaudRate = 31250;
  static const int8_t RxPin = 13;
  static const int8_t TxPin = 22;
};
MIDI_CREATE_CUSTOM_INSTANCE(HardwareSerial, Serial2, MIDI1, SerialMIDISettings);
// MIDI_CREATE_INSTANCE(SoftwareSerial, midiSerial, MIDI);
void setup_MIDI() {
  Serial.println("setup_MIDI debug 00");
  Serial2.begin(31250, SERIAL_8N1, 13, 22);
  // midiSerial.begin(31250); // MIDI baud rate
  // DIN_MIDI.begin(MIDI_CHANNEL_OMNI);

   MIDI1.begin(MIDI_CHANNEL_OMNI); // Listen to all channels

  // MIDI.turnThruOff(); // Disable MIDI thru
  //
  // Send MIDI on message
  Serial.println("setup_MIDI debug 01");
  MIDI1.sendNoteOn(60, 127, 1);  // Note On, C4, velocity 127, channel 1
  delay(500);
  // Send MIDI off message
  MIDI1.sendNoteOn(60, 0, 1);  // Note Off, C4, velocity 127, channel 1
  Serial.println("setup_MIDI debug 02");
}
```

rigr, 2023-02-12:
Just used Serial and that works. So it seems the board (or one of the display libraries) use Serial1 and/or Serial2.
Need to check out how to get the debug Serial-output to a different port.

This works for display AND DIN-serial-output:

To keep my code (more or less) clean I set a link to
setup_MIDI();
inside
void setup(){}

```
struct SerialMIDISettings : public midi::DefaultSettings {
  static const long BaudRate = 31250;
  static const int8_t RxPin = 13;
  static const int8_t TxPin = 22;
};
MIDI_CREATE_CUSTOM_INSTANCE(HardwareSerial, Serial, MIDI1, SerialMIDISettings);
// MIDI_CREATE_INSTANCE(SoftwareSerial, midiSerial, MIDI);
void setup_MIDI() {
  Serial.println("setup_MIDI debug 00");
  Serial.begin(31250, SERIAL_8N1, 13, 22);
  // midiSerial.begin(31250); // MIDI baud rate
  // DIN_MIDI.begin(MIDI_CHANNEL_OMNI);

   MIDI1.begin(MIDI_CHANNEL_OMNI); // Listen to all channels  /////////////////////////  will cause guru medidation

  // MIDI.turnThruOff(); // Disable MIDI thru
  //
  // Send MIDI message
  Serial.println("setup_MIDI debug 01");
  MIDI1.sendNoteOn(60, 127, 1);  // Note On, C4, velocity 127, channel 1
  delay(500);
  // Send MIDI message
  MIDI1.sendNoteOn(60, 0, 1);  // Note Off, C4, velocity 127, channel 1
  Serial.println("setup_MIDI debug 02");
}
```

navivfr, 2023-11-30:
Hello,

I get a TTGO LORA32, and has output pin for UART there is only GPIO 1 & 3 (used for USB serial).
 I need to add a SIM800 (GPRS).
I tried using GPIO 12 & 13... without any success. _(Serial2.begin(115200, SERIAL_8N1, SERIAL2_TX, SERIAL2_RX);_
Does someone know how to use UART with the board ?

thanks

tadam777, 2023-12-01:
Hello, it seems you reversed the TX and RX in your Serial2.begin command.

It should be SerialPort2.begin (BaudRate, SerialMode, **RX_pin, TX_pin**).

You'll find a tutorial on using the serial ports, including using alternative pins here : https://microcontrollerslab.com/esp32-uart-communication-pins-example/

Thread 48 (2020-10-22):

Pin 36, 37, 38, 39 capacitors

ddosoff, 2020-10-22:
Hello LiLyGO,

Today discovered that I can't use SPI_MISO on GPIO 38 and UART RX on GPIO 39 simultaneously.
I checked https://github.com/Xinyuan-LilyGO/TTGO-T-Display/blob/master/schematic/ESP32-TFT(6-26).pdf and found capacitors between 39, 38 and 37, 36 GPIOs.

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

Please describe what purpose of this capacitors?

ddosoff, 2020-10-22:
Can I remove them from PCB?

bradanlane, 2020-12-06:
Thanks @ddosoff - I didn't catch this on my project. I've gone ahead and removed those CAPs.

I hope we get an answer as to their intended function.

tadam777, 2021-01-31:
There's no information about their role in the ESP32 datasheet, but they've got a short description in the ESP32 hardware design guidelines :
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

JFPayeur, 2022-09-19:
My guess is these have a role in touch sensitive switch .. But not shure how

tadam777, 2022-09-19:
I found an article about these capacitors, they're related to an LNA (low noise amplifier) that's actually included on the ESP32, but didn't work well so it was simply removed from the documentation, even if it still exists in the chip.

Someone took the version 1 of the documentation (where it was still described) to find out how to use it.

Full story here : https://github.com/krzychb/esp32-lna

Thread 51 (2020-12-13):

Guru Meditation Error when using print() in macro

Rhombur, 2020-12-13:
Hello,
I got this problem while using the board in an webradio application ( [Edzelf / ESP32-Radio](https://github.com/Edzelf/ESP32-Radio) ). It works fine as long as I do not try to print text information, e.g. the VS1053 decoder board works properly, the web-based interface is up and running and the diplay is recognized and draws the lines defining the segments correctly. Means the radio station plays and I can see the volume bar, but no text is shown.

The display-related definitions are given below:
```
#include <TFT_eSPI.h>

// Color definitions for the screen
#define BLACK   TFT_BLACK
#define BLUE    TFT_BLUE
#define RED     TFT_RED
#define GREEN   TFT_GREEN
#define CYAN    TFT_CYAN
#define MAGENTA TFT_MAGENTA
#define YELLOW  TFT_YELLOW
#define WHITE   TFT_WHITE

TFT_eSPI* tft = NULL ;

// Various macro's to mimic the display functions
#define dsp_setRotation()       tft->setRotation ( 1 )             // Use landscape format (3 for upside down)
#define dsp_fillRect(a,b,c,d,e) tft->fillRect ( a, b, c, d, e )    // Fill a rectange
#define dsp_print(a)            tft->print ( a )                   // Print a string
#define dsp_println(b)          tft->println ( b )                 // Print a string followed by newline
#define dsp_setTextSize(a)      tft->setTextSize( a )              // Set the text size
#define dsp_setTextColor(a)     tft->setTextColor(a)             // Set the text color
#define dsp_setCursor(a,b)      tft->setCursor ( a, b)             // Position the cursor
#define dsp_erase()             tft->fillScreen ( RED )            // Clear the screen
#define dsp_getwidth()          tft->width()                               // Get width of screen
#define dsp_getheight()         tft->height()                                // Get height of screen
#define dsp_update()                                               // Updates to the physical screen
#define dsp_usesSPI()           true                               // Does use SPI

bool dsp_begin()
{
  tft = new TFT_eSPI() ;
  tft->init() ;
  return ( tft != NULL ) ;
  // return false ;
}

#define TFTSECS 4
scrseg_struct     tftdata[TFTSECS] =                        // Screen divided in 3 segments + 1 overlay
{                                                           // One text line is 8 pixels
  { false, WHITE,   0,  8, "" },                            // 1 top line
  { false, CYAN,   20, 64, "" },                            // 8 lines in the middle
  { false, YELLOW, 90, 32, "" },                            // 4 lines at the bottom
  { false, GREEN,  90, 32, "" }                             // 4 lines at the bottom for rotary encoder
} ;
```

The problem pops up if I added the definitions for dsp_print(a); dsp_println(b) as already shown above (to get all the informations on the station etc.). If I try to activate it, the whole thing fails and the messages are:
```
D: Start display
Guru Meditation Error: Core  1 panic'ed (LoadProhibited). Exception was unhandled.
Core 1 register dump:
PC      : 0x400df880  PS      : 0x00060f30  A0      : 0x80158f24  A1      : 0x3ffb1eb0
A2      : 0x3ffb8590  A3      : 0x00000053  A4      : 0x0000001f  A5      : 0x00000053
A6      : 0x3ff65090  A7      : 0x3ff6508c  A8      : 0xfefefefe  A9      : 0x3ffb1e90
A10     : 0x00000053  A11     : 0x00000053  A12     : 0x3ffb86e8  A13     : 0x00000000
A14     : 0x00000000  A15     : 0x3ffb0060  SAR     : 0x0000001c  EXCCAUSE: 0x0000001c
EXCVADDR: 0xfefeff08  LBEG    : 0x400014fd  LEND    : 0x4000150d  LCOUNT  : 0xfffffffa

Backtrace: 0x400df880:0x3ffb1eb0 0x40158f21:0x3ffb1ee0 0x400e2036:0x3ffb1f00 0x400e2119:0x3ffb1f20 0x400d8bdd:0x3ffb1f40 0x400e2fef:0x3ffb1fb0 0x4008a951:0x3ffb1fd0

Rebooting...
```

The exception decoder then yields:
```
PC: 0x400df880: TFT_eSPI::write(unsigned char) at D:\Broesel\Arduino\sketches\libraries\TFT_eSPI\TFT_eSPI.cpp line 3615
EXCVADDR: 0xfefeff08

Decoding stack results
0x400df880: TFT_eSPI::write(unsigned char) at D:\Broesel\Arduino\sketches\libraries\TFT_eSPI\TFT_eSPI.cpp line 3615
0x40158f21: Print::write(unsigned char const*, unsigned int) at C:\Users\Broesel\AppData\Local\Arduino15\packages\esp32\hardware\esp32\1.0.4\cores\esp32\Print.cpp line 42
0x400e2036: Print::write(char const*) at C:\Users\Broesel\AppData\Local\Arduino15\packages\esp32\hardware\esp32\1.0.4\cores\esp32/Print.h line 66
0x400e2119: Print::print(char const*) at C:\Users\Broesel\AppData\Local\Arduino15\packages\esp32\hardware\esp32\1.0.4\cores\esp32\Print.cpp line 89
0x400d8bdd: setup() at D:\Broesel\Arduino\sketches\ESP32-Radio-TTGOv2\Esp32_radio/Esp32_radio.ino line 3364
0x400e2fef: loopTask(void*) at C:\Users\Broesel\AppData\Local\Arduino15\packages\esp32\hardware\esp32\1.0.4\cores\esp32\main.cpp line 14
0x4008a951: vPortTaskWrapper at /home/runner/work/esp32-arduino-lib-builder/esp32-arduino-lib-builder/esp-idf/components/freertos/port.c line 143
```

With my limited knowledge, the problem is triggered when the display is initialized and the first time the dsp_print() is called (last line is Esp32_radio.ino line 3364):
```
dbgprint ( "Start display" ) ;
    if ( dsp_begin() )                                   // Init display
    {
      dsp_setRotation() ;                                // Use landscape format
      dsp_erase() ;                                      // Clear screen
      dsp_setTextSize ( 2 ) ;                            // Small character font
      dsp_setTextColor ( WHITE ) ;                       // Info in white
      dsp_setCursor ( 0, 0 ) ;                           // Top of screen
      dsp_print ( "Starting..." "\n" "Version:" ) ;
```

As the Esp32_radio code works with anumber of different displays that are already supported, I assume that the error is likely somewhere in the TFT_eSPI.cpp. The referenced line 3615 is:
`if (uniCode > pgm_read_word(&gfxFont->last )) return 1;`

as part of the code loading custom fonts:
```
#ifdef LOAD_GFXFF
  } // Custom GFX font
  else {
    if(utf8 == '\n') {
      cursor_x  = 0;
      cursor_y += (int16_t)textsize *
                  (uint8_t)pgm_read_byte(&gfxFont->yAdvance);
    }
    else {
      if (uniCode > pgm_read_word(&gfxFont->last )) return 1;
      if (uniCode < pgm_read_word(&gfxFont->first)) return 1;

      uint16_t   c2    = uniCode - pgm_read_word(&gfxFont->first);
      GFXglyph *glyph = &(((GFXglyph *)pgm_read_dword(&gfxFont->glyph))[c2]);
      uint8_t   w     = pgm_read_byte(&glyph->width),
                h     = pgm_read_byte(&glyph->height);
      if((w > 0) && (h > 0)) { // Is there an associated bitmap?
        int16_t xo = (int8_t)pgm_read_byte(&glyph->xOffset);
        if(textwrapX && ((cursor_x + textsize * (xo + w)) > this->width())) {
          // Drawing character would go off right edge; wrap to new line
          cursor_x  = 0;
          cursor_y += (int16_t)textsize *
                      (uint8_t)pgm_read_byte(&gfxFont->yAdvance);
        }
        if (textwrapY && (cursor_y >= (int32_t)this->height())) cursor_y = 0;
        drawChar(cursor_x, cursor_y, uniCode, textcolor, textbgcolor, textsize);
      }
      cursor_x += pgm_read_byte(&glyph->xAdvance) * (int16_t)textsize;
    }
  }
#endif // LOAD_GFXFF
```

If there is any helpful hint what might trigger this issue, I would be very grateful.

Rhombur, 2020-12-13:
One new finding: the issue can be avoided by an "adaption" to the display setup file (Setup25_TTGO_T_Display.h). Here, line 30 needs to be dissabled:
`// #define LOAD_GFXFF`
Don't know if this line is there by accident or if there is a mistake in the code that tries to load it.

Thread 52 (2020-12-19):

Is my TTGO-T-Display dead or is there a magic trick?

DavidBertet, 2020-12-19:
I just received a TTGO-T-Display. It wasn't doing anything when I plugged it (which isn't normal from what I read), so I decided to push a sample.

Whatever I build from this repo, I always have a part of the screen black, a part green, and a part kind of ugly but correct.

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

Is there a magic trick I missed? Is my screen dead? Could it be another component?

Two things I noticed too:
- the blue LED is not fully bright, it blinks a little bit
- the USB C isn't reversible. it works only in one way, it doesn't power up on the other way
Is that normal?

Thanks!

lewisxhe, 2021-01-14:
Do you mean using the examples provided by this repository to show what it looks like in the picture? It may be that the screen has been damaged.

The blue led light flashes, it means that the battery is not connected. If the battery is connected, it will indicate according to the charging status.

USB, what's wrong, I don't understand

JoeBarouneD, 2021-01-14:
I had same results when i pushed an outdated/bad configurated library.

Be sure to use to correctly install TFT_eSPI and declare the good I2C ports according the sheet.
Don't forget to customize the [User_Setup.h](https://github.com/Xinyuan-LilyGO/TTGO-T-Display/blob/master/TFT_eSPI/User_Setup.h) if you use your own version of TFT_eSPI

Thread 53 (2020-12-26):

I2C Connection problem

GodSmithCS, 2020-12-26:
Hello, I'm new using ESP, but I'm trying to use ADS with the T-display and I can't make the connection. I am using the example of the I2C Scanner and I believe that the wires are correct according to the datasheet.

`
 #include <Wire.h>

 void setup() {
  Wire.begin();

  Serial.begin(9600);
  while (!Serial); // Leonardo: wait for serial monitor
  Serial.println("\nI2C Scanner");
  }

void loop() {
  int nDevices = 0;

  Serial.println("Scanning...");

  for (byte address = 1; address < 127; ++address) {
    Wire.beginTransmission(address);
    byte error = Wire.endTransmission();

    if (error == 0) {
      Serial.print("I2C device found at address 0x");
      if (address < 16) {
      Serial.print("0");
      }
      Serial.print(address, HEX);
      Serial.println("  !");

      ++nDevices;
    } else if (error == 4) {
      Serial.print("Unknown error at address 0x");
      if (address < 16) {
      Serial.print("0");
      }
      Serial.println(address, HEX);
    }
  }
  if (nDevices == 0) {
    Serial.println("No I2C devices found\n");
  } else {
    Serial.println("done\n");
  }
  delay(5000); // Wait 5 seconds for next scan
}
`

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

lewisxhe, 2021-01-14:
Which pin do you use?
You can explicitly initialize the designated I2C pin,
```
Wire.begin(sda,scl)
```
Is your external pull-up resistor 110 ohms? You can use 4.7k or 10k for external pull-up.

tadam777, 2021-02-12:
This board already includes 10k resistors on SDA and SCL :

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

For some reason I'm not able to use the default I2C pin 22, but for example with pins SDA = 21 and SCL = 15 it works flawlessly.

Notice that pins 35 to 39 are input only so they can't be used for I2C.

#define I2C_SDA 21
#define I2C_SCL 15

void setup()
{
	Wire.begin (I2C_SDA, I2C_SCL);
	pinMode (I2C_SDA, INPUT_PULLUP);
	pinMode (I2C_SCL, INPUT_PULLUP);
}

FlyByPC, 2021-02-22:
SCL is defined as pin 23 (not 22) in the board definitions, despite what the pinout diagram says.
Unfortunately, Pin 23 isn't brought out to the pins.

Change the SCL pin definition in C:\Users\<user>\AppData\Local\Arduino15\packages\esp32\hardware\esp32\1.0.4\variants\ttgo-t1\pins_arduino.h and it will work.

lewisxhe, 2021-03-11:
Except for the specified SDA SCL, everything else is the same. I can work normally. Please rule out the problem with the module, or you can try with an I2C device.

```
#include <Wire.h>
#include <Arduino.h>

const uint8_t sda = 21;
const uint8_t scl = 22;

void setup()
{
    Serial.begin(9600);
    Wire.begin(sda, scl);
    while (!Serial); // Leonardo: wait for serial monitor
    Serial.println("\nI2C Scanner");
}

void loop()
{
    int nDevices = 0;
    Serial.println("Scanning...");
    for (byte address = 1; address < 127; ++address) {
        Wire.beginTransmission(address);
        byte error = Wire.endTransmission();

        if (error == 0) {
            Serial.print("I2C device found at address 0x");
            if (address < 16) {
                Serial.print("0");
            }
            Serial.print(address, HEX);
            Serial.println("  !");

            ++nDevices;
        } else if (error == 4) {
            Serial.print("Unknown error at address 0x");
            if (address < 16) {
                Serial.print("0");
            }
            Serial.println(address, HEX);
        }
    }
    if (nDevices == 0) {
        Serial.println("No I2C devices found\n");
    } else {
        Serial.println("done\n");
    }
    delay(5000); // Wait 5 seconds for next scan
}

```

m-stefanski, 2021-11-24:
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

when I am trying to do it this way, LCD screen shows garbage and I2C connection still doesn't work.

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

Tested on PN532 with Adafruit library:

```

#define I2C_SDA 21
#define I2C_SCL 15

void initialize_PN532(){
    Serial.println("Initializing PN532");
    Wire.begin (PN532_SDA, PN532_SCL);
    pinMode (PN532_SDA, INPUT_PULLUP);
    pinMode (PN532_SCL, INPUT_PULLUP);
    nfc.begin();
    uint32_t versiondata = nfc.getFirmwareVersion();
    if (! versiondata) {
        Serial.print("Didn't find PN53x board");
        while (1); // halt
  }
}
```

This happens also when I used pins 26 / 27.

tadam777, 2021-12-11:
In your code you define the **I2C_SDA** and **I2C_SCL**, but then you write Wire.begin (**PN532_SDA**, **PN532_SCL**) so you're probably not using the pins 21 and 15.
Could it be that because of this you're using a pin which is connected to the TFT and this give the random pixels on the screen ?

Have a look at the example above,
#define **I2C_SDA** 21
#define **I2C_SCL** 15

void setup()
{
Wire.begin (**I2C_SDA**, **I2C_SCL**);
pinMode (I2C_SDA, INPUT_PULLUP);
pinMode (I2C_SCL, INPUT_PULLUP);
}

This works for me, even without the two INPUT_PULLUP lines

summerfind, 2023-01-18:
In your code you define the **I2C_SDA** and **I2C_SCL**, but then you write Wire.begin (**PN532_SDA**, **PN532_SCL**) so you're probably not using the pins 21 and 15 that you defined first. Could it be that because of this you're sending SDA/SCL data to another pin which is connected to the TFT and this give the random pixels on the screen ?
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

Hi all, is this too later?
can the config here be able to set other pin than 21/22, let's say 13/14?
Thanks

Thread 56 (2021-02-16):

5V without USB from battery only?

bbogdanmircea, 2021-02-16:
Hello, I have a project where I need to power a device with minimum 4.5V. (CO2 Sensor)
But the 5V pin will drop to battery voltage when there is no USB Power.
Is there any way to have 5V from.the battery with this board?
Or I should buy a small battery boost DCDC converter that I connect in parallel to the battery?
Also VBAT and BAT are the same ?

Docteh, 2021-02-25:
Interesting question, looks like board doesn't have parts to boost voltage.
https://github.com/Xinyuan-LilyGO/TTGO-T-Display/blob/master/schematic/ESP32-TFT(6-26).pdf

At the bottom of schematic they show where the "+5" pad is either battery or "VBUS" from USB. I only saw one reference to BAT, maybe they missed the letter?

Batlapin, 2021-03-13:
1) No boost from LiIon to 5V onboard. Extra boost circuitry should be used.
2) "1" at PWR_EN (IO14) shortens BAT to VBAT (and V3V, TFT communication pins pullups power, to VDD3V3)

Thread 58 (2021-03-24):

Lipo battery connector not working

heng1a, 2021-03-24:
HI
I am just setting up my new ttgo t-display. It works just fine on usb power but when i connect a new fully loaded lipo 1s to the battery connector nothing happens.
On usb the little blue led is blinking quickly, but when i connect lipo and usb the blue led is very bright and not blinking.
It it broken already? Or what is wrong?

CRLRobin, 2022-09-24:
I'm in the same problem, and it will be quite hot nearing the led after I connect an usb cable or a battery.

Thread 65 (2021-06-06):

Deep sleep wake up only over Connect USB

Michaelmilz, 2021-06-06:
Hi,

i have the Problem that my TTGO T-Display Board does not wake up when iam powering that only with the Battery. When i connect the USB cable to the Board, the wakeup over ext0, ext1 or externel Timer works without Problems. For the wakeup i use the Button that Connected to GPIO0. On The other Button (GPIO35) Same Issue. Powering over Battery i only can use Reset Button to bring the Board awake.
Have someone the same issue or an idea what iam doing wrong ?

g-arais, 2021-09-23:
Same with me. The board only wake up by ext0 or ext1 on USB power. When on battery, only reseting. Any sugestions?

Michaelmilz, 2021-09-23:
I solve the problem myself. Because it was long ago I don't know exactly what Iam done.
I figured out that the issue was in the example program. I excluded everything piece by piece until I found the failure code. It may be that the problem was in the analog Measurement of the battery voltage. Write if it helps.

roberbike, 2021-12-29:
Leaving this lines, it is possible to wake up with io34 , battery supply and usb disconnected.

    rtc_gpio_init(GPIO_NUM_14);
    rtc_gpio_set_direction(GPIO_NUM_14, RTC_GPIO_MODE_OUTPUT_ONLY);
	rtc_gpio_set_level(GPIO_NUM_14, 1);
    delay(500);

Jpipe001, 2022-05-04:
Hi,

I've got a TTGO T-Camera (the white version, with a PIR) which won't wake from deep sleep
when powered via a 3.7V LiPo battery attached to the on-board battery connector.

I have written a sketch where the Camera goes to Sleep and then Wakes Up, either when PIR is triggered or after a wait period.

Sleep/Wake behaves completely normally when powered via USB.

But with the battery attached and not powered via USB:
If I let it sleep, then trigger a wake within a few seconds, it works.
If I let it sleep, leave it for ~10 seconds or so, it will not Wake up.

How do I configure this to Wake Up on Battery Power?

Any advice greatly appreciated!

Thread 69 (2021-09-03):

Cannot flash new TTGO-T-Display

cgreening, 2021-09-03:
I've received a new TTGO-T-Display and for some reason, it's not flashing:

I have another TTGO-T-Display board with a dead display that flashes without any problems.

```
esptool.py v3.1
Serial port /dev/cu.usbmodem527E0006811
Connecting.....
Chip is ESP32-D0WDQ6-V3 (revision 3)
Features: WiFi, BT, Dual Core, 240MHz, VRef calibration in efuse, Coding Scheme None
Crystal is 40MHz
MAC: 08:3a:f2:45:34:64
Uploading stub...

A fatal error occurred: Failed to write to target RAM (result was 01070000)
A fatal error occurred: Failed to write to target RAM (result was 01070000)
```

This is what I see with my old board:

```
esptool.py v3.1
Serial port /dev/cu.SLAB_USBtoUART
Connecting........_
Chip is ESP32-D0WDQ6-V3 (revision 3)
Features: WiFi, BT, Dual Core, 240MHz, VRef calibration in efuse, Coding Scheme None
Crystal is 40MHz
MAC: c4:4f:33:7f:f5:b1
Uploading stub...
Running stub...
Stub running...
```

cgreening, 2021-09-04:
After installing some drivers on another issue this has progressed, but not much further:

```
esptool.py v3.1
Serial port /dev/cu.wchusbserial527E0006811
Connecting......
Chip is ESP32-D0WDQ6-V3 (revision 3)
Features: WiFi, BT, Dual Core, 240MHz, VRef calibration in efuse, Coding Scheme None
Crystal is 40MHz
MAC: 08:3a:f2:45:34:64
Uploading stub...

A fatal error occurred: Timed out waiting for packet header
A fatal error occurred: Timed out waiting for packet header
```

cgreening, 2021-09-04:
The device also works perfectly on windows so it's definitely an issue with the Mac driver.

coryb, 2021-10-05:
I had the same issue, I think the key is `/dev/cu.SLAB_USBtoUART` which is created by the SiLabs Driver Disk package.  I installed this previously for a different esp32 devkit, and this drivers seems to conflict with the usb drivers necessary for the TTGO.  I had an application called "CP210xVCPDriver" which was installed by the SiLabs Driver Disk.  I moved that application to the "Trash" and was prompted to  uninstalled the drivers.  After that my TTGO started to work after I reconnected it to my mac.

raybutch, 2022-01-03:
I'm having the same problem. I am unable to flash the TTGO T display module. I am looking for a driver to load on my windows 7 computer. Does anyone know of a driver that will work in a windows?

fmgdias, 2022-01-29:
Connect Pin 2 to GND.

piperov, 2022-04-28:
Similar problem (I think) on a Chromebook. Working in the Linux container, I see a USB device showing up when I connect the TTGO-T-Display board, but no /dev/ttyXXX device gets created.

Conclusion: the USB device on the board fails to be recognized/configured as a Serial Port. Probably a driver issue.

The same procedure, repeated on the same computer, but when running Linux directly on the bare metal, sees a /dev/ttyACM0 created, and then I can program the TTGO-T-Display board, and interact with it in MicroPython (Thonny IDE) without any issue.

Something is fishy with the USB/Serial implementation on the TTGO-T-Display board though.
Could it be the same issue discussed in #47 ?
(https://github.com/Xinyuan-LilyGO/TTGO-T-Display/issues/47)

mianos, 2022-06-06:
You can no longer flash with the CH9102 driver on MacOS Monterey. It sometimes works under Linux. The basic serial port works OK but flashing is hit and miss. I started the kex debugger and it seems to be passing misaligned structures to the API as if it was built with a pre 2018 MacOS driver SDK.

If you have a Windows machine it works 100%.
The WCH driver listed above works on some machines pre Monterey.

It is a bit of a fiasco but one way forward is to flash the additional OTA update configuration on a old Windows machine and then use a proper machine to flash it via wifi.

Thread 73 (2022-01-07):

Not flashing anymore

DaveStu, 2022-01-07:
Hi all. I've had this board for a couple of months with a project I'm working on with someone else.

I've been flashing .bin files with esphome flasher succesfully for the last few months, now suddenly it stops flashing.
The screen will start to flash several times while esphome flasher tries to connect, but it fails, then boots back to previous code and is able to work with last upload, just no new flashing?
I've been all over forums and internet looking for solutions, tried to hold reset, button 1 and/or 2.
Tried different tyep c data cables. I cannot disconnect components because it's all are sodlered in.

I'm now stuck with last code and cannot update our project.
Can I bypass USB and flash via pins, like esp01 with USB flasher?
This has now got me so frustrated.

Any clue anyone?  really strange, all of a sudden.  Thanks

DaveStu, 2022-01-08:
After reluctantly desoldering TTGO board, I was able to flash it again. Then I resoldered it back onto the PCB attached back component at a time, the line elevel converter for LED strips was causing some short or glitch.  I assume it has died or failed somehow.
I've now just left it disconnected and the TTGO flashes and functions fine.

fmgdias, 2022-01-29:
Connect Pin 2 to GND.

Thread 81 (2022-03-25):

GPIO0 button and uploading

stevempotter, 2022-03-25:
Sometimes I can upload new code in Arduino without pressing any buttons, sometimes it aborts flashing code with "Fatal error. Timed out waiting for packet content". Holding down the GPIO0 button seems to fix it but is painful. Is there a way to get around this or make it more reliable to upload without pressing any buttons?

stevempotter, 2022-03-27:
Here is the error I keep getting, even sometimes when I am holding down the GPIO0 button. Any ideas how to prevent this?

```
esptool.py v3.1
Serial port COM23
Connecting......
Chip is ESP32-D0WDQ6 (revision 1)
Features: WiFi, BT, Dual Core, 240MHz, VRef calibration in efuse, Coding Scheme None
Crystal is 40MHz
MAC: 4c:11:ae:a5:f2:98
Uploading stub...
Running stub...
Stub running...
Changing baud rate to 921600
Changed.
Configuring flash size...
Flash will be erased from 0x0000e000 to 0x0000ffff...
Flash will be erased from 0x00001000 to 0x00005fff...
Flash will be erased from 0x00010000 to 0x000b1fff...
Flash will be erased from 0x00008000 to 0x00008fff...
Compressed 8192 bytes to 47...

A fatal error occurred: Timed out waiting for packet content
A fatal error occurred: Timed out waiting for packet content
```

MrMcChip, 2022-03-28:
My first point of focus would be your programming USB cable.
 I have a dedicated 18-in cable that I know has consistent results with
multiple boards using both micro USB and USB-C (with add-on adapter).

On Sun, Mar 27, 2022, 10:20 AM Steve M. Potter ***@***.***>
wrote:

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

stevempotter, 2022-03-28:
On your suggestion, I tried several cables, including some expensive thick well-shielded ones, and short ones. I still can only upload about half of the time. None of them fixed the problem. Sadly, I have gone back to an old DOIT Devkit ESP32 to avoid this problem.

MrMcChip, 2022-03-28:
A lot of troubleshooting is a process of elimination. Other variables to
consider are the board itself so if you have another board to work with or
test? The other simple thing to do is lower the board rate and see if that
shows you anything?

On Mon, Mar 28, 2022, 3:26 PM Steve M. Potter ***@***.***>
wrote:

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

stevempotter, 2022-03-29:
Is there a way to understand this problem and measure something (e.g., with my oscilloscope) to see how to fix it?
I have tried several boards, and the problem is that they all sometimes work and sometimes give the timeout error. An intermittent problem is hard to track down by just trying random changes. My latest tests suggest that if the LilyGO ESP32 board has nothing attached but the USB-C cable, it always uploads. But I don't want to have to unplug the board from its circuits every time I upload new code.

stevempotter, 2022-03-29:
Here are my board settings:
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

MrMcChip, 2022-03-29:
Which UART bridge controller does your board have? Which operating platform
are you running?

On Tue, Mar 29, 2022, 8:15 AM Steve M. Potter ***@***.***>
wrote:

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

stevempotter, 2022-03-30:
> Which UART bridge controller does your board have? Which operating platform
are you running?

I am running Arduino IDE 1.8.15 on Windows10. Here is a photo of the USB chip on the ESP32 that is giving me a hard time.

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

MrMcChip, 2022-03-30:
You have a Sil Lab CP 2104 which is the best available IMO. Get yourself a
datasheet.pdf for that bridge.  You should verify Windows is loading the
proper driver every time you plug in the USB with TTGO board attached
before doing your upload. If you get a timeout recycle the USB connector
with board attached. Windows driver utility should provide that Intel.

*USB sniffer and protocol analyzer for Windows would be my next move to
further troubleshoot USB port communications. This should prove more useful
than an oscilloscope at this point.*
*I operate on a Linux platform... I don't do windows!  So I can't make any
recommendations but there are options available on the web for this type of
utility. *

On Wed, Mar 30, 2022, 3:19 AM Steve M. Potter ***@***.***>
wrote:

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

MrMcChip, 2022-03-30:
Which bridge controller chip is on your DOIT development ESP32 board? Are
they same same as the TTGO?

Also, I believe windows command line prompt will allow you to use the LSUSB
command... If it works in terminal mode/ command line you should see CP210x
listed

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

stevempotter, 2022-03-30:
> Which bridge controller chip is on your DOIT development ESP32 board? Are
they same same as the TTGO?

It looks the same as the SIL 2104 but has no markings whatsoever. Etched off? This DOIT board is probably a clone.

From Windows Device Manager:
Both boards invoke the "Silicon Labs CP210x USB to UART Bridge" driver when plugged in.

> Also, I believe windows command line prompt will allow you to use the LSUSB
> command...

"LSUSB" was not a recognized command at the Terminal command line.

I downloaded "Free Device Monitoring Studio" to look at the USB packets to and from the ESP32. But I have no idea what to look for, and have not used a packet sniffer before. Do you have any suggestions?

MrMcChip, 2022-03-30:
Look into USB device enumeration. It looks like the device and driver are
communicating when given a push button reset when needed. At this point I
would research your CP210X  driver version and see if there's an update
available from silicon labs? I believe your chip is date code 2015?
Again having no desire to give Bill Gates any of my money I'm not a Windows
fan

On Wed, Mar 30, 2022, 8:40 AM Steve M. Potter ***@***.***>
wrote:

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

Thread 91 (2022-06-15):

Connecting External SPI Device RC522

khumprp, 2022-06-15:
Hello

I'm trying to get the RC522 RFID reader to work with TDISPLAY. I have it working with other ESP32 devices.

Right now, the RC522 is being recognized and returns the firmware number successfully, but it will not read cards. I have verified it works on other devices.

MISO - 27
MOSI - 26
CLK - 25
CS - 33
RST - 17

I am setting RST to HIGH, as on other ESP32 devices it reads HIGH and works.

I do not know if I'm missing a step (something maybe to disable SPI on the onboard display) or if there's something different about SPI on this board.

Code below

`
#include <SPI.h>
#include <MFRC522.h>
#include <TFT_eSPI.h>       // Hardware-specific library

#define RST_PIN         17         // Configurable, see typical pin layout above
#define SS_PIN          33         // Configurable, see typical pin layout above

MFRC522 mfrc522(SS_PIN, RST_PIN);  // Create MFRC522 instance

TFT_eSPI tft = TFT_eSPI();  // Invoke custom library

void setup() {
	Serial.begin(9600);		// Initialize serial communications with the PC
	while (!Serial);		// Do nothing if no serial port is opened (added for Arduinos based on ATMEGA32U4)

  pinMode(RST_PIN, OUTPUT);
  digitalWrite(RST_PIN, HIGH);
    Serial.println("HELLO");
  Serial.println(digitalRead(RST_PIN));
  tft.init();

  tft.fillScreen(TFT_WHITE);

	SPI.begin(25,27,26);			// Init SPI bus CLK, MISO, MOSI
	mfrc522.PCD_Init();		// Init MFRC522
	delay(4);				// Optional delay. Some board do need more time after init to be ready, see Readme
	mfrc522.PCD_DumpVersionToSerial();	// Show details of PCD - MFRC522 Card Reader details
	Serial.println(F("Scan PICC to see UID, SAK, type, and data blocks..."));
}

void loop() {
	// Reset the loop if no new card present on the sensor/reader. This saves the entire process when idle.
	if ( ! mfrc522.PICC_IsNewCardPresent()) {
		return;
	}

	// Select one of the cards
	if ( ! mfrc522.PICC_ReadCardSerial()) {
		return;
	}

	// Dump debug info about the card; PICC_HaltA() is automatically called
	mfrc522.PICC_DumpToSerial(&(mfrc522.uid));
}
`

khumprp, 2022-06-16:
Disregard. Turns out I had a bad ground pin. Once I changed to a different ground, it worked fine.

khumprp, 2022-06-16:
Disregard. Turns out I had a bad ground pin. Once I changed to a different ground, it worked fine.

Closed 2022-06-16.

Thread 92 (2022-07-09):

[TTGO T8 ESP32-S2] Sample code fails compiling

Shohreh, 2022-07-09:
Hello,

I'm an Arduino + ESP newbie.

I installed the Arduino 2.0.0rc8 since I read the current stable release (1.8.19) doesn't support that TTGO board.

Then, I [added](https://raw.githubusercontent.com/espressif/arduino-esp32/gh-pages/package_esp32_index.json) and selected that board + port, and [manually installed](https://github.com/Xinyuan-LilyGO/TTGO-T-Display/tree/master/TFT_eSPI) the TFT_eSPI library.

But when I try to compile Arduino\libraries\TFT_eSPI\examples\FactoryTest\FactoryTest.ino, here is what I get:

```
In file included from C:\Users\dummy\Documents\Arduino\libraries\TFT_eSPI\examples\FactoryTest\FactoryTest.ino:1:
c:\Users\dummy\Documents\Arduino\libraries\TFT_eSPI/TFT_eSPI.h:302:21: error: 'VSPI' was not declared in this scope
     uint8_t  port = VSPI;
                     ^~~~
c:\Users\dummy\Documents\Arduino\libraries\TFT_eSPI/TFT_eSPI.h:302:21: note: suggested alternative: 'SPI'
     uint8_t  port = VSPI;
                     ^~~~
                     SPI
C:\Users\dummy\Documents\Arduino\libraries\TFT_eSPI\examples\FactoryTest\FactoryTest.ino: In function 'void setup()':
C:\Users\dummy\Documents\Arduino\libraries\TFT_eSPI\examples\FactoryTest\FactoryTest.ino:212:90: error: 'ADC_WIDTH_BIT_12' was not declared in this scope
     esp_adc_cal_value_t val_type = esp_adc_cal_characterize(ADC_UNIT_1, ADC_ATTEN_DB_11, ADC_WIDTH_BIT_12, 1100, &adc_chars);    //Check type of calibration value used to characterize ADC
                                                                                          ^~~~~~~~~~~~~~~~
C:\Users\dummy\Documents\Arduino\libraries\TFT_eSPI\examples\FactoryTest\FactoryTest.ino:212:90: note: suggested alternative: 'ADC_WIDTH_BIT_13'
     esp_adc_cal_value_t val_type = esp_adc_cal_characterize(ADC_UNIT_1, ADC_ATTEN_DB_11, ADC_WIDTH_BIT_12, 1100, &adc_chars);    //Check type of calibration value used to characterize ADC
                                                                                          ^~~~~~~~~~~~~~~~
                                                                                          ADC_WIDTH_BIT_13
Multiple libraries were found for "SD.h"
  Used: C:\Users\dummy\AppData\Local\Arduino15\packages\esp32\hardware\esp32\2.0.4\libraries\SD
  Not used: C:\Users\dummy\Documents\Arduino\libraries\SD
exit status 1

Compilation error: 'ADC_WIDTH_BIT_12' was not declared in this scope
```

What should I try?

Thank you.

icedawn, 2023-01-25:
Did anyone find a workaround for this?  I'm testing the latest code and examples and still getting this error.

Thanks!

MichKonSher, 2023-01-25:
Same problem

Shohreh, 2023-01-25:
I put it on the back burner, but you might have more luck trying Bodmer's TFT_eSPI instead:

https://github.com/Bodmer/TFT_eSPI/issues/2022

icedawn, 2023-01-25:
Thank you Shoreh.  I was able to solve it with help from https://github.com/teastainGit.  Bottom line, I have T-Display-S3 boards, not TTGO boards -- so Bodmer's and the TTGO libraries weren't going to work until these libraries support the T-Display-S3 board.

Context:  there is a specific TFT_eSPI library provided by LilyGO for the T-Display-S3 at https://github.com/Xinyuan-LilyGO/TTGO-T-Display ... and you need to use the TFT_eSPI contained there.  Worked the first time.  Kudos go to teastainGit for figuring it out and being super helpful!

You can see his notes and our discussion at:  https://github.com/teastainGit/LilyGO-T-display-S3-setup-and-examples/issues/3 for instructions.

Thanks!

Ed

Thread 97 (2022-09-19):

Lowest power consumption

JFPayeur, 2022-09-19:
Closing the screen
    -->  digitalWrite(4, LOW);

 Closing Wifi+BT
      -->   WiFi.disconnect(true);
      -->   WiFi.mode(WIFI_OFF);    // Switch WiFi off

Not reading the bat
   -->  digitalWrite(POWER_EN_PIN, LOW);

And going to deep sleep

Best I can get is ~22ma consumption on the USB

Seems the USB chip put itself to off when not powered, and this is fine
So about 7.7 ma , when reading power from only the Battery ( most relevant metric)

But still 7.7mA, is way to much considering the Esp32 could go in the uA range!
Any other idea ?

Seems to be a firmware available ,,,,
https://github.com/Xinyuan-LilyGO/TTGO-T-Display/tree/master/firmware

I've never done this type of upgrade
Is this to fix this ?

JFPayeur, 2022-09-19:
Did the upload, With this tool
https://www.espressif.com/en/support/download/other-tools

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
It was suprisigly simple

The demo code can demonstrate a power down mode that I mesure down to 0.2mA in deep sleep.
This is cool
But my code still do 7.7mA
Will have to investigate further

oculos, 2023-02-26:
Same problem here.
I get 17-19mA when connected to the USB. I haven't measured it only connected to the battery.

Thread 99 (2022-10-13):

How to power the  TTGO-T-Display without using USB

nielsnl68, 2022-10-13:
Hi,

I would love to use the [TTGO-T-Display](https://github.com/Xinyuan-LilyGO/TTGO-T-Display) without having the usb and battery connected.

I tried to put 5 volt on the 5v pin but that did not work for me. Is there an other solution that i'm missing?

sangngocle, 2022-11-18:
If the 5V pin does not work, you should try the battery port, To make sure 5V won't burn the regulator, you should try to put 4.2V into it first.

Closed 2023-03-13.

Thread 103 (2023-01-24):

Display backlight turns off when powered from LiPo battery

bgarnott, 2023-01-24:
Hi,

I am having an issue with my Lilygo T Display s3 when running on battery. Here is a summary:
1. I can render content to the display when I am powering the T display S3 over USB.
2. I have connected a LiPo battery to the JST connector and the battery charges (as indicated by the orange charge LED) fine.
3. When I have the battery connected and USB connected and I remove the USB connection, the backlight to the display turns off. The display still renders correctly, but I need to shine a light at the display to see what it is displaying.
4. If I reconnect the board to USB, the backlight turns back on and I can again see content on the display.

I have tried adding a ledcWrite(0, 255); call in my main loop to ensure that the backlight pin is being set repeatedly, but this does not help.

Any thoughts what is happening? Is the T Display going into a low power state when running on the battery?

I am using TFT_eSPI to drive the display.

Any help would be greatly appreciated.

Thanks,
Brian.

bgarnott, 2023-01-25:
Hi All,

I have found a solution to this problem: The PWR_EN pin (GPIO_15) needs to be set high to enable the backlight when running on battery. Adding the following lines to my initiatlization function fixed things:

  pinMode(15, OUTPUT);
  digitalWrite(15, HIGH);

Hope this helps out some others.

Brian.

Closed 2023-01-25.

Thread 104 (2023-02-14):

OTA sketch update doesn't work with the T-Display (but works fine with other boards)

Rollmops67, 2023-02-14:
Hello !

I'm using OTA sketch updates on projects with Seeed XIAO ESP32-C3 boards, and it works flawlessy.

Today I wanted to test OTA upload on the T-Display (based on the same "basicOTA.ino" sketch coming with the ESP32 pack).
But it doesn't work,
After having uploaded "basicOTA.ino" a first time through USB, when I try to upload it a second time through OTA, after compiling Arduino IDE 1.8.19 gives me these errors (I'm too noobish to understand the meaning) :

```
Sending invitation to 192.168.1.152
Uploading: [                                                            ] 0%
11:10:23 [ERROR]: Error Uploading
11:10:23 [ERROR]: Error Uploading

processing.app.SerialException: Erreur d'ouverture du port série « 192.168.1.152 ».
	at processing.app.Serial.<init>(Serial.java:152)
	at processing.app.Serial.<init>(Serial.java:82)
	at processing.app.SerialMonitor$2.<init>(SerialMonitor.java:132)
	at processing.app.SerialMonitor.open(SerialMonitor.java:132)
	at processing.app.AbstractMonitor.resume(AbstractMonitor.java:132)
	at processing.app.Editor.resumeOrCloseSerialMonitor(Editor.java:2126)
	at processing.app.Editor.access$1300(Editor.java:116)
	at processing.app.Editor$UploadHandler.run(Editor.java:2095)
	at java.lang.Thread.run(Thread.java:748)
Caused by: jssc.SerialPortException: Port name - 192.168.1.152; Method name - openPort(); Exception type - Port not found.
	at jssc.SerialPort.openPort(SerialPort.java:167)
	at processing.app.Serial.<init>(Serial.java:141)
	... 8 more
Erreur d'ouverture du port série « 192.168.1.152 ».
```
I allready made somme projects with Wifi with the T-Display, no probleme on this side, the Wifi is connecting.
If somebody has a hint, thank you !

Roland

lewisxhe, 2023-03-13:
This has nothing to do with the board. The reason for the failure may be that the partition table you selected does not contain OTA partitions, or the network condition. Please check

Rollmops67, 2023-03-13:
Thank you for the answer !
I have little problems to understand when you say "the partition table you selected".
Can you be a little more precise ?
Thank you !
Roland

lewisxhe, 2023-03-13:
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
As shown in the figure, you can open debug to view the cause of failure and select the partition table correctly

Rollmops67, 2023-03-13:
OK !
It works now, many thanks to you !
With the last ESP32 boards update (2.0.7) for Arduino IDE, the only choice of memory partition is
`16 MB Flash (3MB APP/9.9 MB FATFS)` but it works.
Many thanks again !

Roland

Closed 2023-03-14.

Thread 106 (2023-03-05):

5V output?

oculos, 2023-03-05:
Hi,
I was wondering: Does the T-Display have a step up circuit so that, when operating from a battery, I could get 5V out of the 5V pin? Or is this pin input-only?
Best,
Francis

lewisxhe, 2023-03-13:
5V is only an input, not an output

Closed 2023-03-13.

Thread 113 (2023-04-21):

Display fails when code uploaded by PlatformIO

iconnor, 2023-04-21:
I have a T-Display-S3 that works well but the T-Display ESP32/RP2040 that arrived recently will only show a black screen and failed to print text to it.

My platformoi.ini file:
```ini
[env:esp32dev]
platform = espressif32
board = esp32dev
framework = arduino
monitor_speed = 115200

lib_deps = bodmer/TFT_eSPI

build_flags =
  -Os
  -DCORE_DEBUG_LEVEL=ARDUHAL_LOG_LEVEL_DEBUG
  -DUSER_SETUP_LOADED=1
  ; Define the TFT driver, pins etc here:
  -DST7789_DRIVER=1
  -DTFT_WIDTH=128
  -DTFT_HEIGHT=160
  -DTFT_MOSI=19
  -DTFT_SCLK=18
  -DTFT_CS=5
  -DTFT_DC=16
  -DLOAD_FONT2=1
  -DLOAD_FONT4=1
  -DLOAD_FONT6=1
  -DLOAD_FONT7=1
  -DLOAD_FONT8=1
  -DLOAD_GFXFF=1
  -DSMOOTH_FONT=1
  -DSPI_FREQUENCY=27000000
```

main.cpp
```cpp

#define TFT_BL	4
#define I2C_SDA	21
#define I2C_SCL	22
#define ADC_IN	34
#define BUTTON1	35
#define BUTTON2	0

#include <SPI.h>
#include <TFT_eSPI.h>

TFT_eSPI tft = TFT_eSPI();

void setup(void) {
  Serial.begin(115200);

  Serial.println("Started up");

  tft.init();
  tft.setSwapBytes(true);
  tft.setRotation(0);
  tft.fillScreen(TFT_BLACK);
  Serial.println("Screen filled black");
  tft.setCursor(0, 0);
  tft.setTextColor(TFT_WHITE);
  Serial.println("Text colour set but we never get to the next step");

  // We should be able to print text now
  tft.println("Never gets to this step");
  Serial.println("Printed text");
}

void loop(void) {
}
```

```bash
Wrote 313008 bytes (172800 compressed) at 0x00010000 in 4.6 seconds (effective 545.3 kbit/s)...
Hash of data verified.

Leaving...
Hard resetting via RTS pin...
======================================================= [SUCCESS] Took 12.23 seconds =======================================================
--- Terminal on /dev/cu.usbserial-56440195251 | 115200 8-N-1
--- Available filters and text transformations: colorize, debug, default, direct, esp32_exception_decoder, hexlify, log2file, nocontrol, printable, send_on_enter, time
--- More details at https://bit.ly/pio-monitor-filters
--- Quit: Ctrl+C | Menu: Ctrl+T | Help: Ctrl+T followed by Ctrl+H
Screen init
Screen filled white
Screen filled black
Cursor set
Text colour set
Printed text
```

I can see the Serial.println but the screen remains black. Thanks.

iconnor, 2023-04-21:
Once I changed the platformio.ini to this it started to work:
```ini
[env:esp32dev]
platform = espressif32
board = esp32dev
framework = arduino
monitor_speed = 115200

lib_deps = bodmer/TFT_eSPI

build_flags =
  -Os
  -DCORE_DEBUG_LEVEL=ARDUHAL_LOG_LEVEL_DEBUG
  -DUSER_SETUP_LOADED=1
  ; Define the TFT driver, pins etc here:
  -DST7789_DRIVER=1
  -DTFT_WIDTH=135
  -DTFT_HEIGHT=240
  -DTFT_MOSI=19
  -DTFT_SCLK=18
  -DTFT_SDA=21
  -DTFT_SCL=22
  -DTFT_CS=5
  -DTFT_BL=4
  -DTFT_DC=16
  -DLOAD_FONT2=1
  -DLOAD_FONT4=1
  -DLOAD_FONT6=1
  -DLOAD_FONT7=1
  -DLOAD_FONT8=1
  -DLOAD_GFXFF=1
  -DSMOOTH_FONT=1
  -DSPI_FREQUENCY=27000000
```

Closed 2023-04-21.

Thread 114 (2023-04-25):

I2C Connection Issue with PN532

JpEncausse, 2023-04-25:
Hi, I have an Issue reading PN532 from I2C.

```
Looking for PN532...
Found chip PN532
Firmware ver. 1.6
[  2550][E][Wire.cpp:513] requestFrom(): i2cRead returned Error 263
```

I don't think it is the wireing or the NFC board because it see it. I do think it might be something related with TTGO-T-Display that might use the Wire also ?

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

```
#include <Arduino.h>

// ------------------------------------------
//  TFT_eSPI
// ------------------------------------------

#include <TFT_eSPI.h>
#define ADC_EN    14  //ADC_EN is the ADC detection enable port
TFT_eSPI tft = TFT_eSPI(135, 240);

void setupTFT() {
  Serial.print("Setup TFT");

  pinMode(ADC_EN, OUTPUT);
  digitalWrite(ADC_EN, HIGH);

  tft.init();
  tft.setRotation(1);
  tft.setCursor(0, 0);
  tft.fillScreen(TFT_BLACK);
  tft.setTextDatum(MC_DATUM);

  tft.setTextSize(2);
  tft.drawString("TFT is Ready", tft.width() / 2, tft.height() / 2);
}

// ------------------------------------------
//  NFC
//  https://github.com/elechouse/PN532
// ------------------------------------------

#define I2C_SDA   21
#define I2C_SCL   22

#include <Wire.h>
#include <PN532_I2C.h>
#include <PN532.h>
#include <NfcAdapter.h>

PN532_I2C pn532i2c(Wire);
//PN532 nfc(pn532i2c);
NfcAdapter nfc = NfcAdapter(pn532i2c);

bool setupNFC(){
    Wire.begin(I2C_SDA, I2C_SCL);
    Serial.println("Looking for PN532...");
    nfc.begin();

    return true;
}

void loopNFC(){
    delay(100);
    if (nfc.tagPresent()) {
        NfcTag tag = nfc.read();
        tag.print();
    }
}

// ------------------------------------------
//  LOOP
// ------------------------------------------

void setup() {
  Serial.begin(115200);
  delay(1000);

  // Setup the TFT display
  setupTFT();

  // Setup the NFC
  setupNFC();
}

void loop() {
  //loopNFC();
  delay(500);
}
```

I'm using PlatformIO with ElectroHouse library loaded  aside.

```
[env]
platform = espressif32
framework = arduino
monitor_speed = 115200

[env:ttgo-lora32-v1]
extends = env
board = ttgo-lora32-v1
lib_deps =
	bodmer/TFT_eSPI@^2.5.23
```

JpEncausse, 2023-04-30:
Playing around with many variables it seems to works (mostly)
I assume the board is somehow buggy.

Closed 2023-04-30.

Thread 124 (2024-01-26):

LilyGo T display won't mount.

richp-tech, 2024-01-26:
My new LilyGo T display won't mount. I have installed the driver, it shows up in the USB tree, it turns on but won't mount.

MacBook Air Sonoma 14.2.1

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

https://github.com/Xinyuan-LilyGO/TTGO-T-Display/assets/59874838/2aeb0c9d-b6b9-445e-b769-7c5deb869761

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

richp-tech, 2024-01-26:
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

Both drivers definitely installed. Still no good.

richp-tech, 2024-01-26:
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
Strangely there are TWO devices with the same serial number (two drivers?) but it isn't mounted.

richp-tech, 2024-01-29:
This is the box. So I believe it is a T display

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

richp-tech, 2024-01-29:
Fixed
My fault
Header file conflict https://github.com/Xinyuan-LilyGO/TTGO-T-Display/assets/59874838/3317fb33-2f39-4cef-b7e9-7028a49ccc87

Closed 2024-01-29.

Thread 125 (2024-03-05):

TTGO T-Display v1.1 serial port problems

jeffryr, 2024-03-05:
I bought a few TTGO T-Display v1.1 modules awhile back and put them in a drawer.  When I exhausted my supply of the older boards, I discovered that I couldn't communicate with the newer boards.  Debian 12 doesn't recognize the CH9102F USB to UART Bridge controller.  I built the driver from https://github.com/WCHSoftGroup/ch343ser_linux, did the usual modprobe ch343 and tried this with two different v1.1 devices.  They both boot and run the factory firmware but never show up as a serial device, dmesg reveals the following:
```
[   90.808423] ch343: loading out-of-tree module taints kernel.
[   90.808528] ch343: module verification failed: signature and/or required key missing - tainting kernel
[   90.810623] usbcore: registered new interface driver usb_ch343
[   90.810626] ch343: USB serial driver for ch342/ch343/ch344/ch347/ch9101/ch9102/ch9103/ch9104, etc.
[   90.810628] ch343: V1.8 On 2024.02
[  118.167362] usb 2-1.1: new full-speed USB device number 4 using ehci-pci
[  118.247365] usb 2-1.1: device descriptor read/64, error -32
[  118.435388] usb 2-1.1: device descriptor read/64, error -32
[  118.623367] usb 2-1.1: new full-speed USB device number 5 using ehci-pci
[  118.703358] usb 2-1.1: device descriptor read/64, error -32
[  118.891385] usb 2-1.1: device descriptor read/64, error -32
[  118.999644] usb 2-1-port1: attempt power cycle
[  119.603361] usb 2-1.1: new full-speed USB device number 6 using ehci-pci
[  120.019370] usb 2-1.1: device not accepting address 6, error -32
[  120.099362] usb 2-1.1: new full-speed USB device number 7 using ehci-pci
[  120.515369] usb 2-1.1: device not accepting address 7, error -32
[  120.515625] usb 2-1-port1: unable to enumerate USB device
[  189.079929] usb 2-1-port1: Cannot enable. Maybe the USB cable is bad?
```
This is with a known good cable.  Also tried loading the driver on Windows 10, it just reports a malfunction when the device is plugged in.  Has anyone gotten these to work with any OS?

degagevip, 2024-05-07:
我也碰到了相同问题，角上有一个蓝色的灯在闪，我焊在了PCB上面拆下来很难。

JackJack261, 2024-06-04:
Im also having a similar issue I think. I tried uploading a sketch, and ever since my PC has trouble recognizing the device. I can't get the device to connect to any ports that Arduino IDE can recognize, even after trying to install the driver recommended in the README. Have you found a solution yet?

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

Image of the device in my device manager for reference

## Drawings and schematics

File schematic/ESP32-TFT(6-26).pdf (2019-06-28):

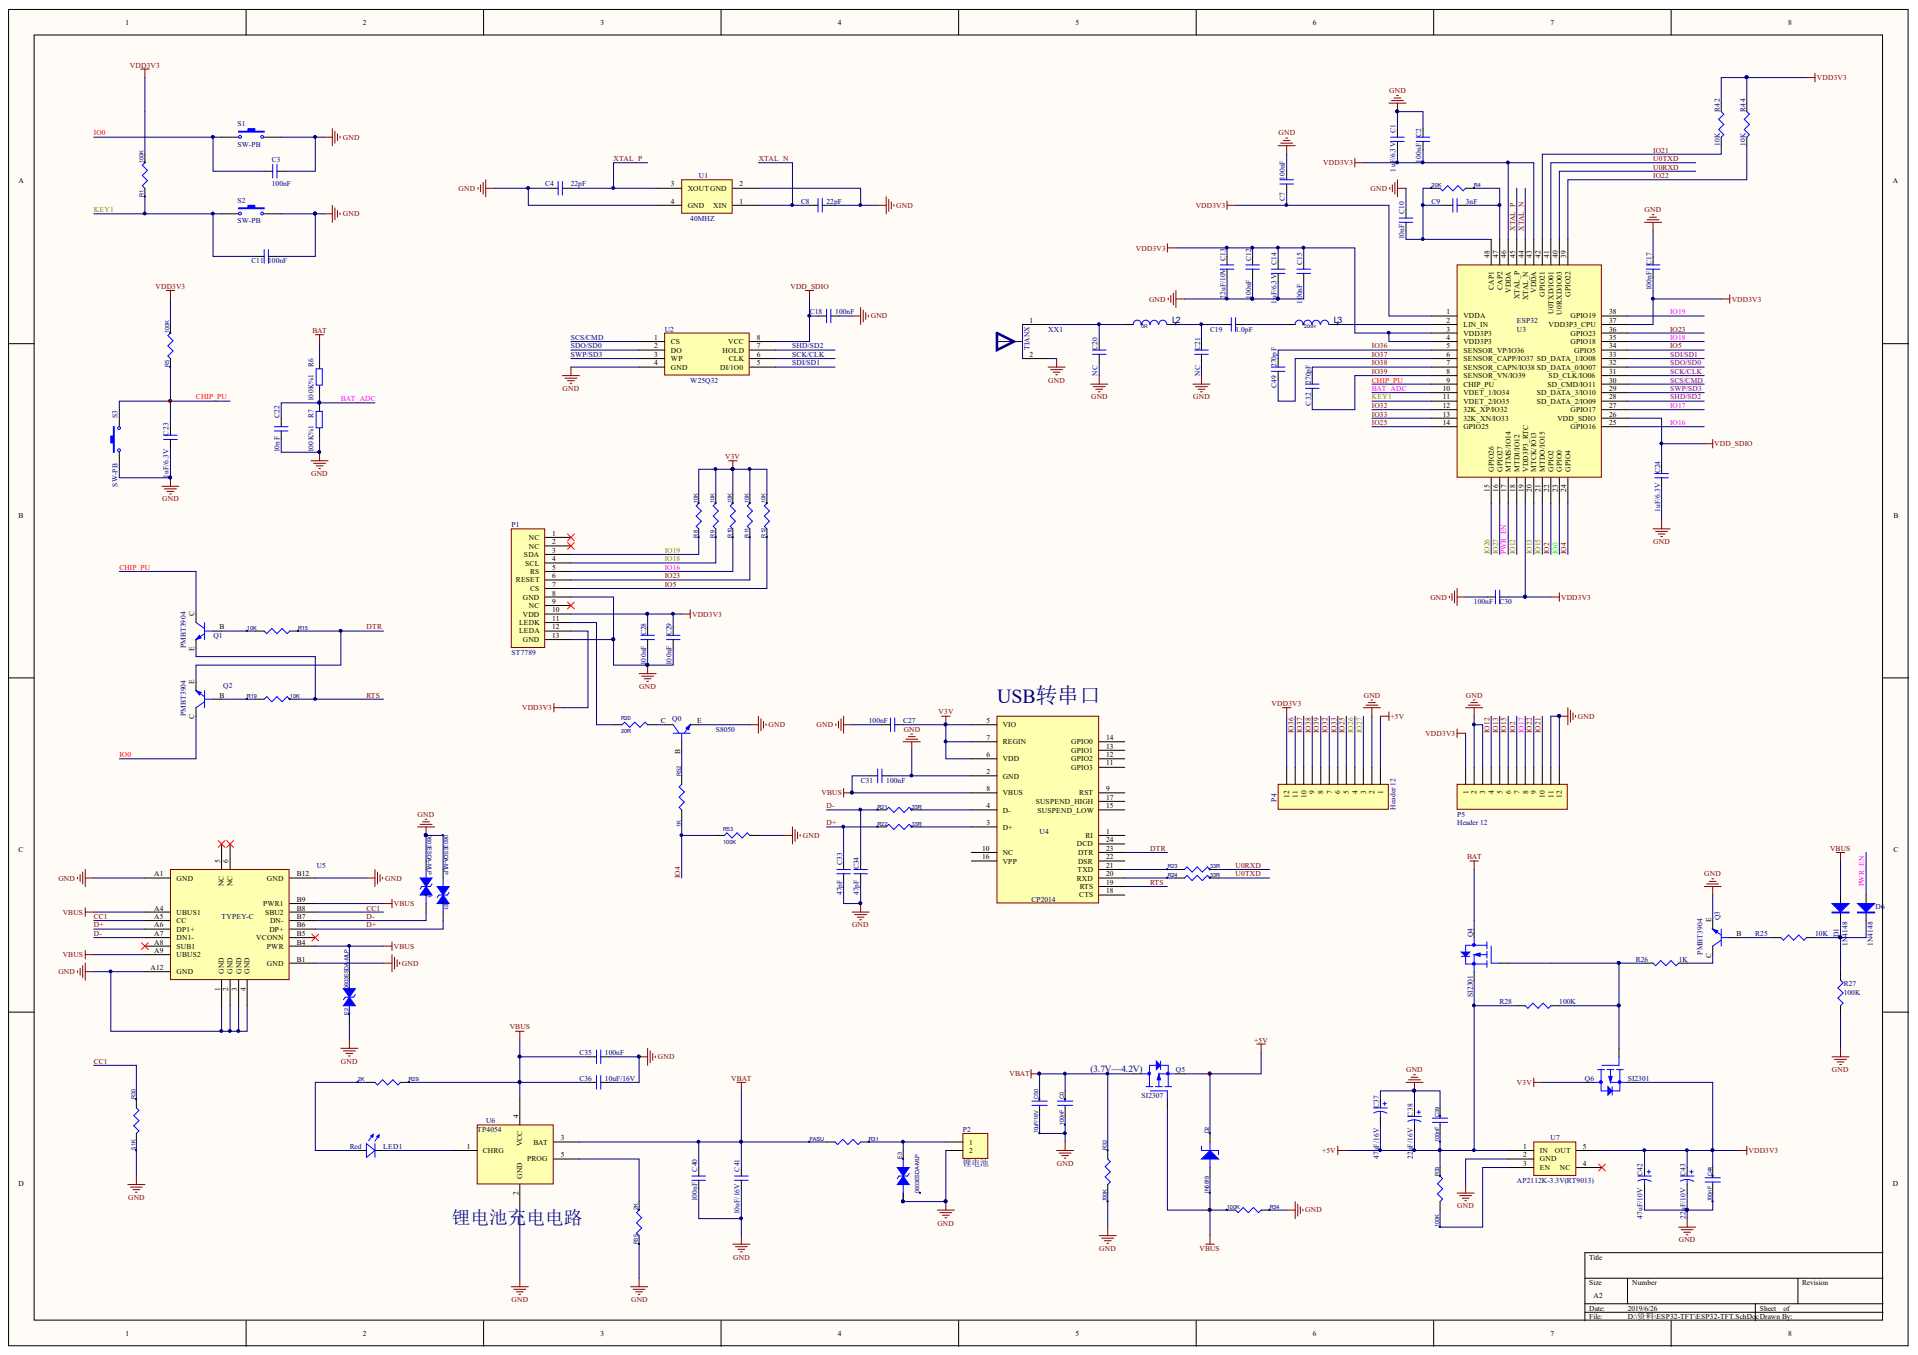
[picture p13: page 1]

CHIP_P U | 9

VPP 16 C 10

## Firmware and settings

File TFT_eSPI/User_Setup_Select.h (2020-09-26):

// This header file contains a list of user setup files and defines which one the
// compiler uses when the IDE performs a Verify/Compile or Upload.
//
// Users can create configurations for different Espressif boards and TFT displays.
// This makes selecting between hardware setups easy by "uncommenting" one line.

// The advantage of this hardware configuration method is that the examples provided
// with the library should work with different setups immediately without any other
// changes being needed. It also improves the portability of users sketches to other
// hardware configurations and compatible libraries.
//
// Create a shortcut to this file on your desktop to permit quick access for editing.
// Re-compile and upload after making and saving any changes to this file.

// Customised User_Setup files are stored in the "User_Setups" folder.

#ifndef USER_SETUP_LOADED //  Lets PlatformIO users define settings in
//  platformio.ini, see notes in "Tools" folder.

// Only ONE line below should be uncommented.  Add extra lines and files as needed.

// #include <User_Setup.h>           // Default setup is root library folder

//#include <User_Setups/Setup1_ILI9341.h>  // Setup file configured for my ILI9341
//#include <User_Setups/Setup2_ST7735.h>   // Setup file configured for my ST7735
//#include <User_Setups/Setup3_ILI9163.h>  // Setup file configured for my ILI9163
//#include <User_Setups/Setup4_S6D02A1.h>  // Setup file configured for my S6D02A1
//#include <User_Setups/Setup5_RPi_ILI9486.h>        // Setup file configured for my stock RPi TFT
//#include <User_Setups/Setup6_RPi_Wr_ILI9486.h>     // Setup file configured for my modified RPi TFT
//#include <User_Setups/Setup7_ST7735_128x128.h>     // Setup file configured for my ST7735 128x128 display
//#include <User_Setups/Setup8_ILI9163_128x128.h>    // Setup file configured for my ILI9163 128x128 display
//#include <User_Setups/Setup9_ST7735_Overlap.h>     // Setup file configured for my ST7735
//#include <User_Setups/Setup10_RPi_touch_ILI9486.h> // Setup file configured for ESP8266 and RPi TFT with touch

//#include <User_Setups/Setup11_RPi_touch_ILI9486.h> // Setup file configured for ESP32 and RPi TFT with touch
//#include <User_Setups/Setup12_M5Stack.h>           // Setup file for the ESP32 based M5Stack
//#include <User_Setups/Setup13_ILI9481_Parallel.h>  // Setup file for the ESP32 with parallel bus TFT
//#include <User_Setups/Setup14_ILI9341_Parallel.h>  // Setup file for the ESP32 with parallel bus TFT
//#include <User_Setups/Setup15_HX8357D.h>           // Setup file configured for HX8357D (untested)
//#include <User_Setups/Setup16_ILI9488_Parallel.h>  // Setup file for the ESP32 with parallel bus TFT
//#include <User_Setups/Setup17_ePaper.h>            // Setup file for any Waveshare ePaper display
//#include <User_Setups/Setup18_ST7789.h>            // Setup file configured for ST7789

//#include <User_Setups/Setup19_RM68140_Parallel.h>  // Setup file configured for RM68140 with parallel bus

//#include <User_Setups/Setup20_ILI9488.h>           // Setup file for ESP8266 and ILI9488 SPI bus TFT
//#include <User_Setups/Setup21_ILI9488.h>           // Setup file for ESP32 and ILI9488 SPI bus TFT

//#include <User_Setups/Setup22_TTGO_T4.h>           // Setup file for ESP32 and TTGO T4 version 1.2
//#include <User_Setups/Setup22_TTGO_T4_v1.3.h>      // Setup file for ESP32 and TTGO T4 version 1.3
//#include <User_Setups/Setup23_TTGO_TM.h>           // Setup file for ESP32 and TTGO TM ST7789 SPI bus TFT
//#include <User_Setups/Setup24_ST7789.h>            // Setup file configured for ST7789 240 x 240
#include <User_Setups/Setup25_TTGO_T_Display.h>    // Setup file for ESP32 and TTGO T-Display ST7789V SPI bus TFT
//#include <User_Setups/Setup26_TTGO_T_Wristband.h>  // Setup file for ESP32 and TTGO T-Wristband ST7735 SPI bus TFT

//#include <User_Setups/Setup27_RPi_ST7796_ESP32.h>    // ESP32   RPi MHS-4.0 inch Display-B
//#include <User_Setups/Setup28_RPi_ST7796_ESP8266.h>  // ESP8266 RPi MHS-4.0 inch Display-B

//#include <User_Setups/Setup29_ILI9341_STM32.h>          // Setup for Nucleo board
//#include <User_Setups/Setup30_ILI9341_Parallel_STM32.h> // Setup for Nucleo board and parallel display
//#include <User_Setups/Setup31_ST7796_Parallel_STM32.h>  // Setup for Nucleo board and parallel display
//#include <User_Setups/Setup32_ILI9341_STM32F103.h>      // Setup for "Blue/Black Pill"

//#include <User_Setups/Setup33_RPi_ILI9486_STM32.h>      // Setup for Nucleo board

//#include <User_Setups/Setup34_ILI9481_Parallel_STM32.h> // Setup for Nucleo board and parallel display
//#include <User_Setups/Setup35_ILI9341_STM32_Port_Bus.h> // Setup for STM32 port A parallel display

//#include <User_Setups/Setup36_RPi_touch_ILI9341.h>      // Setup file configured for ESP32 and RPi TFT with touch

//#include <User_Setups/Setup43_ST7735.h>            // Setup file configured for my ST7735S 80x160
//#include <User_Setups/Setup44_TTGO_CameraPlus.h>   // Setup file for ESP32 and TTGO T-CameraPlus ST7789 SPI bus TFT    240x240
//#include <User_Setups/Setup45_TTGO_T_Watch.h>      // Setup file for ESP32 and TTGO T-Watch ST7789 SPI bus TFT  240x240

//#include <User_Setups/Setup135_ST7789.h>           // Setup file for ESP8266 and ST7789 135 x 240 TFT

//#include <User_Setups/SetupX_Template.h>


#endif // USER_SETUP_LOADED



/////////////////////////////////////////////////////////////////////////////////////
//                                                                                 //
//     DON'T TINKER WITH ANY OF THE FOLLOWING LINES, THESE ADD THE TFT DRIVERS     //
//       AND ESP8266 PIN DEFINITONS, THEY ARE HERE FOR BODMER'S CONVENIENCE!       //
//                                                                                 //
/////////////////////////////////////////////////////////////////////////////////////


// Identical looking TFT displays may have a different colour ordering in the 16 bit colour
#define TFT_BGR 0   // Colour order Blue-Green-Red
#define TFT_RGB 1   // Colour order Red-Green-Blue

// Legacy setup support, RPI_DISPLAY_TYPE replaces RPI_DRIVER
#if defined (RPI_DRIVER)
#if !defined (RPI_DISPLAY_TYPE)
#define RPI_DISPLAY_TYPE
#endif
#endif

// Legacy setup support, RPI_ILI9486_DRIVER form is deprecated
// Instead define RPI_DISPLAY_TYPE and also define driver (e.g. ILI9486_DRIVER)
#if defined (RPI_ILI9486_DRIVER)
#if !defined (ILI9486_DRIVER)
#define ILI9486_DRIVER
#endif
#if !defined (RPI_DISPLAY_TYPE)
#define RPI_DISPLAY_TYPE
#endif
#endif
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

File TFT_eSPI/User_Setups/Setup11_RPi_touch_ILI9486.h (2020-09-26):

// See SetupX_Template.h for all options available
#define RPI_DISPLAY_TYPE
#define ILI9486_DRIVER // 20MHz maximum SPI

#define TFT_MISO 19
#define TFT_MOSI 23
#define TFT_SCLK 18
#define TFT_CS   15  // Chip select control pin
#define TFT_DC    2  // Data Command control pin
#define TFT_RST   4  // Reset pin (could connect to RST pin)
//#define TFT_RST  -1  // Set TFT_RST to -1 if display RESET is connected to ESP32 board RST

#define TOUCH_CS 22     // Chip select pin (T_CS) of touch screen


#define LOAD_GLCD   // Font 1. Original Adafruit 8 pixel font needs ~1820 bytes in FLASH
#define LOAD_FONT2  // Font 2. Small 16 pixel high font, needs ~3534 bytes in FLASH, 96 characters
#define LOAD_FONT4  // Font 4. Medium 26 pixel high font, needs ~5848 bytes in FLASH, 96 characters
#define LOAD_FONT6  // Font 6. Large 48 pixel font, needs ~2666 bytes in FLASH, only characters 1234567890:-.apm
#define LOAD_FONT7  // Font 7. 7 segment 48 pixel font, needs ~2438 bytes in FLASH, only characters 1234567890:.
#define LOAD_FONT8  // Font 8. Large 75 pixel font needs ~3256 bytes in FLASH, only characters 1234567890:-.
#define LOAD_GFXFF  // FreeFonts. Include access to the 48 Adafruit_GFX free fonts FF1 to FF48 and custom fonts

#define SMOOTH_FONT


#define SPI_FREQUENCY  20000000

#define SPI_TOUCH_FREQUENCY  2500000

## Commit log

2020-04-15 Added eagle footprint
2020-04-15 Adds Pin 17 to eagle footprint
2020-06-29 Add SD card to demonstrate how to use the second SPI device
2020-09-26 Modified structure, friendly to novices
    [Configuring options.txt]
2021-12-26 Update Import
    fix esp_adc_cal.h import
    [FactoryTest.ino]
2022-02-06 Fix for issue #65
    [FactoryTest.ino]
2022-04-18 3D Shell file
    [prt0003_23.stl, prt0005_14(2).stl]
2022-08-13 Add files via upload
    Add KiCad symbol and footprint
2022-08-13 Update README.MD
    Add README.MD to KiCad library
